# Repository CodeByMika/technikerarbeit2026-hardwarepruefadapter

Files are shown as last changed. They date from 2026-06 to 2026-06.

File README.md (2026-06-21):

# 🛠️ Hardware Prüfadapter







> **Portfolio-Projekt:** Dieses Repository enthält die vollständige Hard- und Softwareentwicklung eines universellen Hardware-Prüfadapters. Das Projekt entstand als Abschluss-/Technikerprojekt im Rahmen meiner Ausbildung zum staatlich geprüften Techniker Elektrotechnik (Profil: Softwareentwicklung).

---

## 📖 Projektübersicht

Der Hardware Prüfadapter ist ein Embedded-System auf Basis eines ESP32-S3, das entwickelt wurde, um externe Hardwarekomponenten und Baugruppen automatisiert zu testen und zu simulieren. Das System stellt eine Brücke zwischen analoger/digitaler Hardware und modernen Web-Technologien dar.

Das Hauptaugenmerk der Entwicklung lag auf einer **sauberen Systemarchitektur (Clean Architecture)**, extremer Ausfallsicherheit (Fail-Safe-Mechanismen) und einer hohen Testabdeckung durch systemunabhängiges Unit-Testing (TDD).

<p align="center">
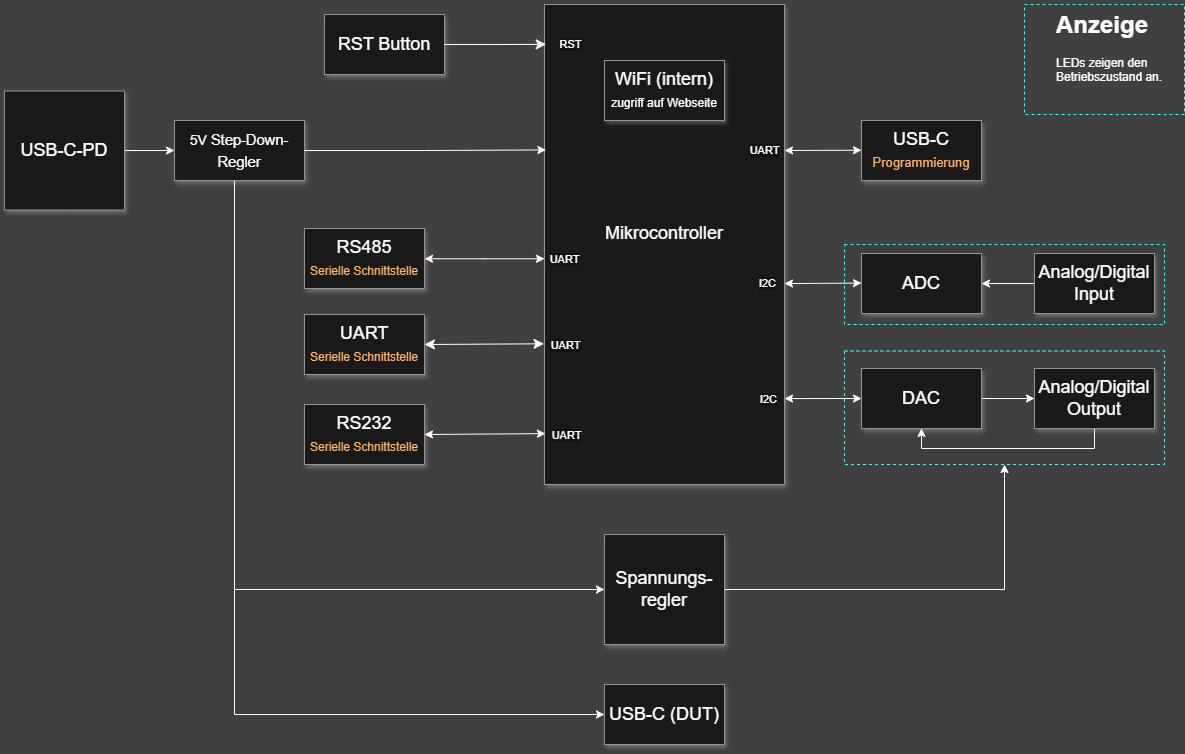
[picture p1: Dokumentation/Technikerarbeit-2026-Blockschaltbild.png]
Blockschaltbild
  

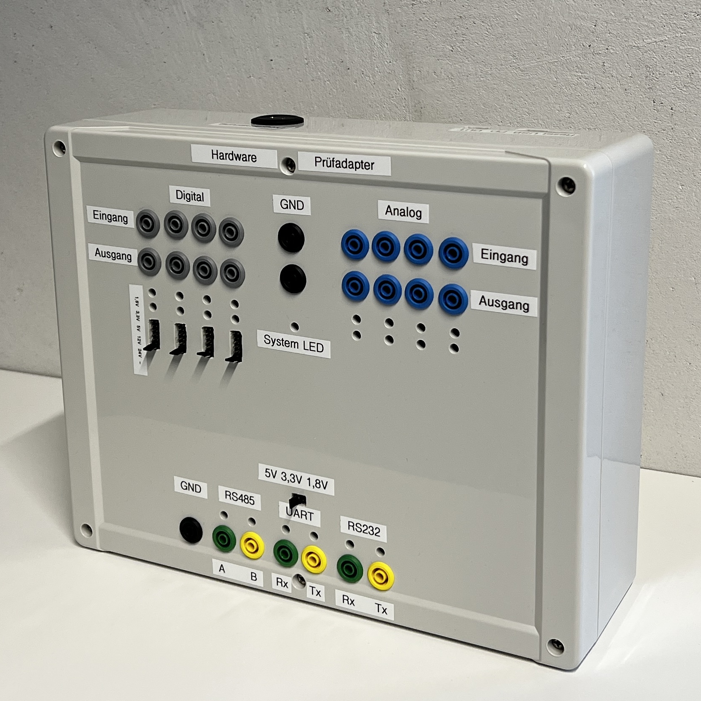
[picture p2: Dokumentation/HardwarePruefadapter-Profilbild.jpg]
Prüfadapter
  
  
  </p>

## ✨ Kernfunktionen & Features

### 💻 Software (VS Code)
* **Clean Architecture:** Strikte Trennung von Hardware-Treibern (Adaptern) und Business-Logik. Alle Logik-Komponenten sind plattformunabhängig in C++17 geschrieben.
* **Web-Dashboard:** Eine eingebettete Single-Page-Application (HTML/CSS/JS) direkt auf dem Mikrocontroller zur Steuerung und Überwachung der I/Os.
* **RESTful OpenAPI:** Bereitstellung einer API zur Automatisierung sowie Server-Sent Events (SSE) für ein Live-Terminal und Echtzeit-Log-Streaming.

### 🔌 Hardware (KiCad)
* **Herzstück:** ESP32-S3 für Netzwerkkommunikation und Logik.
* **Peripherie über I²C:**
  * ADCs (ADS1115) für Spannungsmessung.
  * DAC (DAC8574) zur Ausgabe analoger Spannung.
  * LED-Treiber (LP5018) für das Status-Feedback direkt am Gerät.
* **Externe Schnittstellen:** UART, RS232, RS485 für externe Gerätekommunikation.
>**Wichtig:** Hardwareänderungshinweise beachten, diese sind in der V1.0 nicht enthalten.

## 🏗️ Software-Architektur

Die Firmware basiert auf dem **EVA-Prinzip** (Eingabe - Verarbeitung - Ausgabe) und läuft in einem deterministischen Zyklus.

1. **Input Sequence:** Auslesen der ADCs, serielle Puffer leeren, asynchrone Befehle aus der Web-API (`Mailbox`) abholen.
2. **Process Sequence:** Abgleich der Daten im `ProcessImager`, Anwenden der Filter, Auswerten der Safety-Regeln (Überspannung, Kurzschluss).
3. **Output Sequence:** Setzen der DACs, Schalten der physikalischen GPIOs, Update der Status-LEDs.

Alle Hardware-Abhängigkeiten werden über Interfaces injiziert (Dependency Injection), wodurch die gesamte Logik auf dem PC simuliert und mit **GoogleTest** geprüft werden kann.

## 🛠️ Lokale Entwicklung & Testing

Das Projekt nutzt **PlatformIO** und ein `Makefile` für reibungslose Entwicklung unter Linux/WSL2 und Windows.

## 👨‍💻 Über den Autor

Dieses Projekt dient als praktischer Nachweis meiner Fähigkeiten im Bereich der hardwarenahen Softwareentwicklung, Systemarchitektur und Schaltungsentwicklung.

## ⚖️ Rechtliches & Haftungsausschluss (Disclaimer)

**Zweck des Projekts:** Dieses Projekt wurde ausschließlich zu Bildungs- und Demonstrationszwecken im Rahmen einer Weiterbildung zum staatlich geprüften Techniker entwickelt. Es handelt sich hierbei **nicht** um ein geprüftes, zertifiziertes oder für den produktiven Einsatz im industriellen oder privaten Umfeld zugelassenes Endprodukt.

**Haftungsausschluss:** Die Nutzung der in diesem Repository bereitgestellten Informationen, Quellcodes (Software) und Hardware-Designs (Schaltpläne, Gerber-Daten, KiCad-Files) erfolgt **ausschließlich auf eigene Gefahr**.

* Der Autor übernimmt keinerlei Gewähr für die Aktualität, Korrektheit, Vollständigkeit, Qualität oder Sicherheit der bereitgestellten Informationen.
* Haftungsansprüche gegen den Autor, welche sich auf Schäden materieller, immaterieller, personeller oder finanzieller Art beziehen, die durch die Nutzung oder Nichtnutzung der dargebotenen Informationen bzw. durch die Nutzung fehlerhafter und unvollständiger Informationen verursacht wurden, sind grundsätzlich ausgeschlossen.
* Beim Nachbau oder Betrieb der Hardware wird mit teilweise gefährlichen elektrischen Spannungen gearbeitet. Ein Nachbau darf nur von qualifiziertem Fachpersonal unter Einhaltung geltender VDE- und Sicherheitsvorschriften durchgeführt werden.

**Urheberrecht:** Alle Rechte an diesem Projekt, dem Quellcode und dem Hardware-Design liegen, sofern nicht anders durch Lizenzen von Drittanbietern angegeben (z.B. Bibliotheken im `/lib` Ordner), beim Autor.

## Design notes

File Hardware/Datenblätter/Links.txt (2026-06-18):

ZDiode_24V_mmsz5225_to_mmsz5267		https://www.mouser.de/ProductDetail/Vishay/MMSZ5226C-HE3_A-08?qs=Imq1NPwxi774wPyD3tjngw%3D%3D

MOSFETs:

24V:
TSM05N03		https://www.reichelt.de/de/de/shop/produkt/mosfet_n-ch_30v_5a_0_046r_sot-223-254918	
TSM042N03CS		https://www.reichelt.de/de/de/shop/produkt/mosfet_n-ch_30v_30a_7w_0_0042r_so-8-379909
IRF 7832PbF		https://www.reichelt.de/de/de/shop/produkt/mosfet_n-ch_30v_20a_2_5w_so-8-129794
IRLR8743PbF		https://www.reichelt.de/de/de/shop/produkt/mosfet_n-ch_30v_160a_135w_to-251aa-90380

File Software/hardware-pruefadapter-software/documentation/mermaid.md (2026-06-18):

```mermaid
flowchart LR
    %% Styling der Blöcke
    classDef ext fill:#f9f9f9,stroke:#666,stroke-width:2px,color:#333
    classDef switch fill:#ffebee,stroke:#c62828,stroke-width:2px,color:#b71c1c
    classDef ctrl fill:#2b4a7d,stroke:#1a2b4c,stroke-width:2px,color:#fff
    classDef power fill:#e7f9e7,stroke:#2b7d4a,stroke-width:2px,color:#1a4c2b
    classDef config fill:#fff3e0,stroke:#d48806,stroke-width:2px,color:#875604,stroke-dasharray: 5 5

    %% Nodes
    USBC["<b>USB-C Buchse</b>"]:::ext
    Switch{"<b>Schalter</b>"}:::switch
    Matrix[/"<b>Widerstandsmatrix</b><br/>(Spannungs- & Stromlimit)"/]:::config
    PDCtrl{{"<b>USB-PD Controller</b>"}}:::ctrl
    
    Reg5V["<b>Hauptregler</b><br/>(5V)"]:::power
    
    subgraph Verteilung ["Spannungsverteilung"]
        direction TB
        StepUp["<b>Step-Up Wandler</b><br/>(12V / 24V)"]:::power
        StepDown["<b>Step-Down Wandler</b><br/>(3,3V / 1,8V)"]:::power
    end

    %% Verbindungen
    USBC <==> Switch
    Switch <==>|"PD-Protokoll<br/>Aushandlung"| PDCtrl
    
    Matrix -.->|"konfiguriert"| PDCtrl
    
    PDCtrl ===>|"VBUS<br/>(max. 15V / 3,9 A)"| Reg5V
    
    Reg5V ===>|5V| StepUp
    Reg5V ===>|5V| StepDown

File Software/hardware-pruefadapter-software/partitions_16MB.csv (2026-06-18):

# Name | Type | SubType | Offset | Size | Flags
nvs | data | nvs |  | 0x6000
phy_init | data | phy |  | 0x1000
otadata | data | ota |  | 0x2000
app0 | app | factory |  | 6M
app1 | app | ota_0 |  | 6M
spiffs | data | spiffs |  | 3M
coredump | data | coredump |  | 64K

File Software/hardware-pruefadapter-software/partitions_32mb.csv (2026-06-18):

# Name | Type | SubType | Offset | Size | Flags
nvs | data | nvs |  | 0x6000
phy_init | data | phy |  | 0x1000
otadata | data | ota |  | 0x2000
app0 | app | factory |  | 2M
app1 | app | ota_0 |  | 10M
app2 | app | ota_1 |  | 10M
spiffs | data | spiffs |  | 9M
coredump | data | coredump |  | 64K

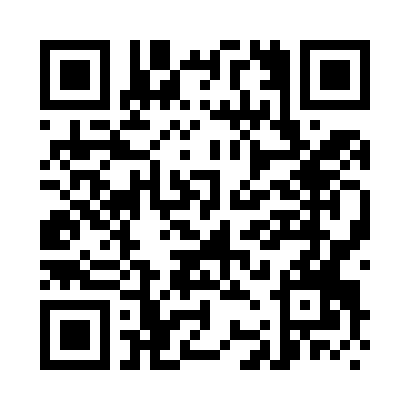
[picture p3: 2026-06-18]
Software/hardware-pruefadapter-software/demo/1_WLAN_Login.png

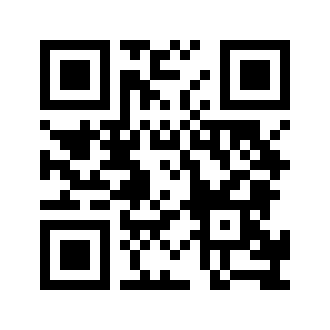
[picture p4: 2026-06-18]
Software/hardware-pruefadapter-software/demo/2_Dashboard_Link.png

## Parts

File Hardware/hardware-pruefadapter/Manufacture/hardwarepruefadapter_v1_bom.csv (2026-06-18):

Designator | Footprint | Quantity | Value | LCSC Part #
C1001, C1002, C1004, C303 | 0805 | 4 | 1uF/50V | C28323
C1003, C1006, C1008, C804, C806 | 0805 | 5 | 10uF/25V | C15850
C1005, C1007, C1009, C1301, C1302, C1303, C1304, C1305, C203, C204, C205, C401, C405, C502, C602, C803, C805, C905, C908 | 0805 | 19 | 100nF/50V | C1711
C1101, C201, C802, C807 | 1206 | 4 | 100uF/6.3V | C15008
C1201, C202 | 1206 | 2 | 100nF/50V | C24497
C301, C302 | 1206 | 2 | 4.7uF/25V | C1872
C304 | 1206 | 1 | 1uF/50V | C1848
C305, C306 | 0603 | 2 | 100nF/50V | C14663
C307, C308 | 0603 | 2 | 1uF/50V | C15849
C402, C403, C404, C413, C415 | 1206 | 5 | 4.7uF/50V | C29823
C406 | 0805 | 1 | 100pF/50V | C1790
C407 | 1206 | 1 | 47uF/10V | C96123
C408, C409 | 0805 | 2 | 2.2uF/25V | C19110
C410 | 1206 | 1 | 10uF/16V | C1849
C411 | 1206 | 1 | 22uF/25V | C12891
C412 | 0805 | 1 | 3.3pF/50V | C170106
C414, C419 | 0805 | 2 | 4.7pF/50V | C1820
C416, C417 | 0805 | 2 | 4.7uF/25V | C1779
C418 | 0805 | 1 | 680pF/50V | C1754
C501, C503, C505, C506, C601, C603, C605, C606, C901, C902, C906, C907, C909, C910, C911, C912 | 0805 | 16 | 1µF/50V | C28323
D1001, D1002, D1003, D1004, D1005, D1006, D1007, D1008, D1009, D1010, D1011, D1012, D1013, D1014, D1015, D1016, D1017 | WL-SFTW_3528_PLCC4 | 17 | 150352M173300 | C6785090
D1101, D1203, D1303 | WL-SMCW_0603_Yellow | 3 | 150060YS75000 | C6784997
D1102, D1204, D1304 | WL-SMCW_0603_Green | 3 | 150060GS75000 | C5252984
D1201, D1202 | D_SMA | 2 | SMAJ12A | C28613
D1301, D1302 | D_SMA | 2 | SMAJ15CA | C46985
D301 | D_SMA | 1 | SMAJ20A | C10763
D302 | D_SMA | 1 | SMAJ15A | C23424
D304 | WL-SMSW_1204_A | 1 | E6C1204VGAC1UDA | C375482
D401, D402 | DIO_BAS716_115 | 2 | BAS716,115 | C282366
D403 | D_SOD-323F | 1 | PMEG4010CEJ,115 | C50704
D501, D502, D503, D504, D601, D602, D603, D604, D801, D802, D803, D804, D901, D902, D903, D904, D905, D906, D907, D908 | TSOT-23 | 20 | BAV199LT1G | C145516
D701, D703, D705, D707, D709, D711, D713, D715 | SOT95P240X111-3N | 8 | BZX84C10LT1G | C82476
D702, D706, D710, D714 | D_SMA | 4 | SMAJ5.0A | C10758
D704, D708, D712, D716 | D_SMA | 4 | SMAJ24A | C10769
D805 | D_SMA | 1 | SMAJ26A | C49370
F1201, F1202 | 1206 | 2 | 1206L010/60WR | C2153714
F801, F802, F803, F804 | FUSC1607X85N | 4 | 0ZCM0002FF2G | C5299556
IC1001, IC1002, IC1003 | VQFN-32_LP5018RSMR | 3 | LP5018RSMR | C2653373
J1101 | 61300621121 | 1 | 6130XX21121_61300621121 | C5140604
J1102, J1201, J1301 | PHOENIX_1861933 | 3 | 1861933 | C5483323
J1202 | PHOENIX_1933192 | 1 | 1933192 | C5266027
J201, J202, J203, J204 | 61201621621 | 4 | 5103308-3 | C305956
J301, J401 | AMPHENOL_12402012E212A | 2 | 12402012E212A | C5150972
J402 | PHOENIX_1861946 | 1 | 1861946 | C6368767
J501, J601, J710, J801 | PHOENIX_1861959 | 4 | 1861959 | C6656102
J702, J704, J706, J708 | 61301221121 | 4 | 6130XX21121_61301221121 | C6699258
L1201, L1202 | 1206 | 2 | CBM321609U181T | C391192
L301, L303 | WE-MPSB_1812 | 2 | WE-MPSB_1812 | C5155961
L302 | WE-MAPI_4020 | 1 | XAL4020-122MEC | C19191653
L401 | INDDFN750X750X310-2N | 1 | 3.3uH | C5448588
L402 | WE-LQS_3015 | 1 | 10uH | C1329386
L403 | WE-LQS_5020 | 1 | 10uH | C7193153
Q301 | SOT-23 | 1 | BSS123 | C8491
Q701, Q702, Q703, Q704, Q705, Q706, Q707, Q708 | SOT-23 | 8 | BS170FTA | C5236685
R1001, R1002, R1008, R515, R615, R922, R928 | 0805 | 7 | 3.3k | C26010
R1003, R1004, R1005, R1009, R1010, R1201, R210, R301, R305, R407, R420, R421, R509, R609, R701, R704, R705, R706, R708, R710, R711, R712, R714, R715, R716, R717, R719, R720, R721, R723, R724, R725, R726, R728, R729, R730, R732, R733, R734, R735, R737, R738, R812 | 0805 | 43 | 10k | C149881
R1011, R1012, R1013, R1014, R505, R604, R801, R813, R903, R904 | 0805 | 10 | 0R | C17477
R1101 | 0805 | 1 | 1M | C17514
R1102, R208, R209, R802, R807, R816, R823 | 0805 | 7 | 200k | C17539
R1103 | 0805 | 1 | 360K | C17645
R1104, R1105, R1107, R1108 | 0805 | 4 | 4.7k | C17673
R1106, R404, R806, R815, R822, R827 | 0805 | 6 | 20K | C4328
R1109, R1110, R1203, R1204, R1301, R1302, R315, R503, R508, R516, R519, R603, R608, R616, R619, R739, R740, R741, R742, R905, R906, R911, R912, R924, R925, R931, R933 | 0805 | 27 | 1k | C17513
R1202 | 1206 | 1 | 1R | C17928
R1205 | 0805 | 1 | 390R | C17655
R202, R203, R204, R205, R206, R207, R211, R212, R513, R613, R919, R923 | 0805 | 12 | 2.2k | C17520
R302 | 0805 | 1 | 51k | C17737
R303 | 0603 | 1 | 1k | C21190
R304 | 0603 | 1 | 10k | C25804
R306 | 0603 | 1 | 4.7k | C23162
R308, R309, R312 | 0603 | 3 | 5.1k | C23186
R310, R311 | 0603 | 2 | 0R | C15402
R313 | 0603 | 1 | 2.4k | C22940
R405 | 0805 | 1 | 68k | C17801
R406, R418 | 0805 | 2 | 5.1k | C27834
R410, R417 | 0805 | 2 | 100k | C149504
R411, R502, R506, R514, R518, R602, R606, R614, R618, R901, R902, R909, R910, R920, R921, R929, R930 | 0805 | 17 | 150k | C17470
R412 | 0805 | 1 | 110k | C17422
R415 | 0805 | 1 | 1.3M | C26109
R416 | 0805 | 1 | 180k | C101955
R419 | 0805 | 1 | 160k | C17485
R422, R423 | 0805 | 2 | 56k | C17756
R424 | 1206 | 1 | 0R | C17888
R504, R512, R517, R520, R605, R612, R617, R620, R804, R814, R819, R824, R907, R908, R913, R916, R926, R927, R932, R934 | 0805 | 20 | 30k | C17621
R702 | 1206 | 1 | 1k | C4410
R703, R709, R713, R718, R722, R727, R731, R736 | RESC3216X125N | 8 | 0ZCJ0010FF2E | C194142
R707 | 1206 | 1 | 24k | C17960
R803, R805, R817, R818 | 2512 | 4 | 330R | C19866
S201 | 4363X10458XX | 1 | 436331045822 | C6089591
U1101, U202, U203 | SOP65P400X130-8N | 3 | LSF0102DCTR | C132024
U1201 | SOTFL50P160X60-8N | 1 | THVD1406DR | C5215918
U1202 | MFSOP6-4_4.4x3.6mm_P1.27mm | 1 | TLP175A(TPL,E | C141522
U1301 | SOP65P640X120-16N | 1 | TRS3232EIPWR | C2652868
U301 | SOIC127P600X175-8N | 1 | IRF9358TRPBF | C537847
U302 | USON-10_2.5x1.0mm_P0.5mm | 1 | TPD4EUSB30DQAR | C90627
U303 | QFN-24-1EP_4x4mm_P0.5mm_EP2.75x2.75mm | 1 | CYPD3177-24LQXQ | C2959321
U401 | CONV_TPS56637RPAR | 1 | TPS56637RPAR | C841386
U402 | SOT-23-5 | 1 | TLV75801PDBVT | C2868412
U403 | SOT-23-5 | 1 | TPS61041DBVR K | C9846
U404 | SON65P200X200X80-7N | 1 | TPS61170DRVR | C15163
U502, U602, U903, U904 | TSSOP-10_3x3mm_P0.5mm | 4 | ADS1115IDGST | C468683
U701, U702, U703, U704, U705, U706, U707, U708 | SOT103P240X110-3N | 8 | DMP3130L-7 | C155233
U802, U804 | SOIC127P600X175-8N | 2 | OPA2990IDR | C2058283
U803 | SOP65P640X120-16N | 1 | DAC8574IPWR | C2864663
VR401 | VREG_LM1117MPX-3.3_NOPB | 1 | LM1117MPX-3.3/NOPB | C9662

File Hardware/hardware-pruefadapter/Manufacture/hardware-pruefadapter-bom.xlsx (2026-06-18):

ID | Bezeichner | Footprint | Stückzahl | Bezeichnung | Anbieter und Referenz
1 | R502,R902,R602,R606,R618,R909,R411,R901,R920,R614,R930,R514,R910,R518,R506,R921,R929 | R_0805_2012Metric | 17 | 150k
2 | R1303,R1206,R501,R402,R1006,R403,R424,R1007,R408,R401,R935,R414,R1111,R409 | R_1206_3216Metric | 14 | 0R
3 | D903,D907,D503,D602,D801,D601,D803,D804,D904,D908,D504,D902,D905,D502,D501,D906,D901,D604,D603,D802 | DIO_BAV99 | 20 | BAV99
4 | S201 | 4363X10458XX | 1 | 436331045822
5 | R919,R613,R513,R923 | R_0805_2012Metric | 4 | 2,2K
6 | R209,R1102,R802,R823,R208,R807,R816 | R_0805_2012Metric | 7 | 200k
7 | R713,R718,R731,R736,R709,R703,R722,R727 | RESC3216X125N | 8 | 0ZCJ0010FF2E
8 | C414,C419 | C_0805_2012Metric | 2 | 4.7pF
9 | R735,R720,R721,R738,R737,R1003,R705,R609,R1004,R723,R407,R726,R808,R734,R712,R732,R701,R729,R728,R730,R717,R1009,R509,R421,R714,R1005,R210,R809,R706,R305,R301,R810,R715,R420,R708,R716,R1201,R724,R725,R710,R711,R733,R812,R704,R811,R1010,R719 | R_0805_2012Metric | 47 | 10k
10 | D705,D713,D703,D701,D707,D715,D711,D709 | SOT95P240X111-3N | 8 | BZX84C10LT1G
11 | R805,R818,R817,R803 | R_2512_6332Metric | 4 | 330
12 | R932,R908,R504,R517,R804,R512,R913,R916,R934,R927,R814,R617,R620,R612,R520,R907,R819,R605,R926,R824 | R_0805_2012Metric | 20 | 30k
13 | R415 | R_0805_2012Metric | 1 | 1,3M
14 | R516,R933,R1302,R739,R1110,R925,R924,R503,R1109,R508,R1203,R905,R1301,R931,R741,R608,R906,R911,R519,R912,R315,R619,R616,R603,R740,R1204,R742 | R_0805_2012Metric | 27 | 1k
15 | R303 | R_0603_1608Metric | 1 | 1k
16 | U1202 | MFSOP6-4_4.4x3.6mm_P1.27mm | 1 | TLP175A
17 | U703,U701,U705,U702,U708,U707,U704,U706 | SOT103P240X110-3N | 8 | DMP3130L-7
18 | C1008,C804,C1003,C1006,C806 | C_0805_2012Metric | 5 | 10uF
19 | C205,C203,C401,C1009,C204,C1007,C405,C1005 | C_0805_2012Metric | 8 | 100nF
20 | R1012,R604,R903,R904,R1013,R1014,R505,R1011 | R_0805_2012Metric | 8 | 0
21 | C1002,C1004,C1001 | C_0805_2012Metric | 3 | 1uF
22 | J601,J501,J801,J710 | PHOENIX_1861959 | 4 | 1861959
23 | C901,C506,C501,C606,C909,C911,C907,C906,C503,C601,C902,C605,C912,C910,C603,C505 | C_0805_2012Metric | 16 | 1µF
24 | R203,R204,R207,R202,R205,R212,R211,R206 | R_0805_2012Metric | 8 | 2,2k
25 | J1102,J1301,J1201 | PHOENIX_1861933 | 3 | 1861933
26 | R1002,R1001,R1008 | R_0805_2012Metric | 3 | 3,3k
27 | D712,D708,D704,D716 | D_SMA | 4 | SMAJ24A
28 | R1101 | R_0805_2012Metric | 1 | 1M
29 | C412 | C_0805_2012Metric | 1 | 3.3pF
30 | R1105,R1104,R1108,R1305,R1207,R1107,R1304,R1208 | R_0805_2012Metric | 8 | 4,7k
31 | D1201,D1202 | D_SMA | 2 | SMAJ12A
32 | L302 | WE-MAPI_4020 | 1 | WE-MAPI_4020
33 | D702,D706,D714,D710 | D_SMA | 4 | SMAJ5.0A
34 | R826,R813,R201,R801,R413,R825 | R_0805_2012Metric | 6 | 0R
35 | R1106 | R_0805_2012Metric | 1 | 20K
36 | R302 | R_0805_2012Metric | 1 | 51k
37 | J1302,J403 | PinHeader_1x06_P2.54mm_Vertical | 2 | Conn_01x06_Pin
38 | R1205 | R_0805_2012Metric | 1 | 390R
39 | J205 | 61301421121 | 1 | Conn_02x07_Counter_Clockwise
40 | R422,R423 | R_0805_2012Metric | 2 | 56k
41 | R419 | R_0805_2012Metric | 1 | 160k
42 | C502,C803,C1302,C1304,C1305,C905,C908,C1303,C1301,C805,C602 | C_0805_2012Metric | 11 | 0.1uF
43 | R928,R922,R615,R515 | R_0805_2012Metric | 4 | 3,3K
44 | C201,C802,C1101,C807 | C_1206_3216Metric | 4 | 100uF
45 | D302 | D_SMA | 1 | SMAJ15A
46 | R702 | R_1206_3216Metric | 1 | 1k
47 | C306,C305 | C_0603_1608Metric | 2 | 100nF
48 | C407 | C_1206_3216Metric | 1 | 47uF
49 | R601 | R_1206_3216Metric | 1 | 0
50 | Q703,Q704,Q707,Q701,Q706,Q705,Q708,Q702 | SOT-23 | 8 | BS170FTA
51 | R406,R418 | R_0805_2012Metric | 2 | 5,1k
52 | U1201 | SOTFL50P160X60-8N | 1 | THVD1406DR
53 | U401 | CONV_TPS56637RPAR | 1 | TPS56637RPAR
54 | U301 | SOIC127P600X175-8N | 1 | IRF9358TRPBF
55 | U1301 | SOP65P640X120-16N | 1 | TRS3232EIPWR
56 | L402 | L_1206_3216Metric | 1 | 6.8µH
57 | U404 | SON65P200X200X80-7N | 1 | TPS61170DRVR
58 | C307,C308 | C_0603_1608Metric | 2 | 1uF
59 | F801,F804,F802,F803 | FUSC1607X85N | 4 | 0ZCM0002FF2G
60 | C301 | C_1206_3216Metric | 1 | 4uF/25V
61 | C1201,C202 | C_1206_3216Metric | 2 | 100nF
62 | U903,U502,U904,U602 | TSSOP-10_3x3mm_P0.5mm | 4 | ADS1115IDGS
63 | R827,R404,R815,R822,R806 | R_0805_2012Metric | 5 | 20k
64 | U303 | QFN-24-1EP_4x4mm_P0.5mm_EP2.75x2.75mm | 1 | CYPD3177-24LQXQ
65 | R707 | R_1206_3216Metric | 1 | 24k
66 | C406 | C_0805_2012Metric | 1 | 100pF
67 | R307,R314,R311,R310 | R_0603_1608Metric | 4 | 0
68 | Q301 | SOT-23 | 1 | BSS123
69 | D805 | D_SMA | 1 | SMAJ26A
70 | L1201,L1202 | L_1206_3216Metric | 2 | 180R
71 | U403 | SOT-23-5 | 1 | TPS61041DDC
72 | TP302 | TestPoint_Pad_D1.5mm | 1 | TestPoint_VBUS-SW
73 | C402,C403,C404 | C_1206_3216Metric | 3 | 4u7
74 | C413 | C_1206_3216Metric | 1 | 4.7uF / 25V
75 | J202,J204,J201,J203 | 61201621621 | 4 | 6120XX21621_61201621621
76 | R416 | R_0805_2012Metric | 1 | 180k
77 | J402 | PHOENIX_1861946 | 1 | 1861946
78 | TP202,TP201 | TestPoint_Pad_D1.5mm | 2 | ~
79 | U203,U1101,U202 | SOP65P400X130-8N | 3 | LSF0102DCTR
80 | U802,U804 | SOIC127P600X175-8N | 2 | OPA2990IDR
81 | C417 | C_0805_2012Metric | 1 | 4.7uF / 16V
82 | D1301,D1302 | D_SMA | 2 | SMAJ15CA
83 | C415 | C_1206_3216Metric | 1 | 4.7uF
84 | J301,J401 | AMPHENOL_12402012E212A | 2 | 12402012E212A
85 | D402,D401 | DIO_BAS716_115 | 2 | BAS716_115
86 | F1202,F1201 | Fuse_1206_3216Metric | 2 | Polyfuse_Small
87 | U302 | USON-10_2.5x1.0mm_P0.5mm | 1 | TPD4EUSB30
88 | R306 | R_0603_1608Metric | 1 | 4k7
89 | C410 | C_1206_3216Metric | 1 | 10uF
90 | TP203 | TestPoint_Pad_D1.5mm | 1 | GPIO43
91 | R312,R308,R309 | R_0603_1608Metric | 3 | 5k1
92 | VR401 | VREG_LM1117MPX-3.3_NOPB | 1 | LM1117MPX-3.3_NOPB
93 | R405 | R_0805_2012Metric | 1 | 68k
94 | L303,L301 | WE-MPSB_1812 | 2 | WE-MPSB_1812
95 | TP301 | TestPoint_Pad_D1.5mm | 1 | TestPoint_VBUS
96 | C409,C408 | C_0805_2012Metric | 2 | 2.2uF
97 | C303 | C_0805_2012Metric | 1 | 1u
98 | R412 | R_0805_2012Metric | 1 | 110k
99 | C416 | C_0805_2012Metric | 1 | 4.7uF
100 | U402 | SOT-23-5 | 1 | TLV75801PDBV
101 | R417,R410 | R_0805_2012Metric | 2 | 100k
102 | C302 | C_1206_3216Metric | 1 | 4u7/25V
103 | L403 | L_1206_3216Metric | 1 | 10µH
104 | D301 | D_SMA | 1 | SMAJ20A
105 | R1103 | R_0805_2012Metric | 1 | 360K
106 | R304 | R_0603_1608Metric | 1 | 10k
107 | J1202 | PHOENIX_1933192 | 1 | 1933192
108 | L401 | L_1206_3216Metric | 1 | 3.3uH
109 | C418 | C_0805_2012Metric | 1 | 680pF
110 | TP204 | TestPoint_Pad_D1.5mm | 1 | GPIO44
111 | R1202 | R_1206_3216Metric | 1 | 1R
112 | D403 | D_SOD-323F | 1 | PMEG4010CEJ
113 | U201 | ESP32-S3-DEVKITC-1-N8R8 | 1 | ESP32-S3-DEVKITC-1
114 | C304 | C_1206_3216Metric | 1 | 1u
115 | C411 | C_1206_3216Metric | 1 | 22uF
116 | R313 | R_0603_1608Metric | 1 | 2k4
117 | U803 | SOP65P640X120-16N | 1 | DAC8574IPWR
118 | D304 | WL-SMSW_1204_A | 1 | WL-SMSW_1204_A
119 | D1006,D1008,D1003,D1005,D1004,D1009,D1001,D1013,D1015,D1012,D1007,D1011,D1010,D1016,D1017,D1014,D1002 | WL-SFTW_3528_PLCC4 | 17 | WL-SFTW_3528_PLCC4
120 | J706,J708,J704,J702 | 61301221121 | 4 | 6130XX21121_61301221121
121 | D1204,D1102,D1304 | WL-SMCW_0603_Green | 3 | WL-SMCW_0603_Green
122 | D1303,D1101,D1203 | WL-SMCW_0603_Yellow | 3 | WL-SMCW_0603_Yellow
123 | IC1001,IC1002,IC1003 | SOP50P490X110-28N | 3 | LP5018DGSR
124 | J1101 | 61300621121 | 1 | 6130XX21121_61300621121

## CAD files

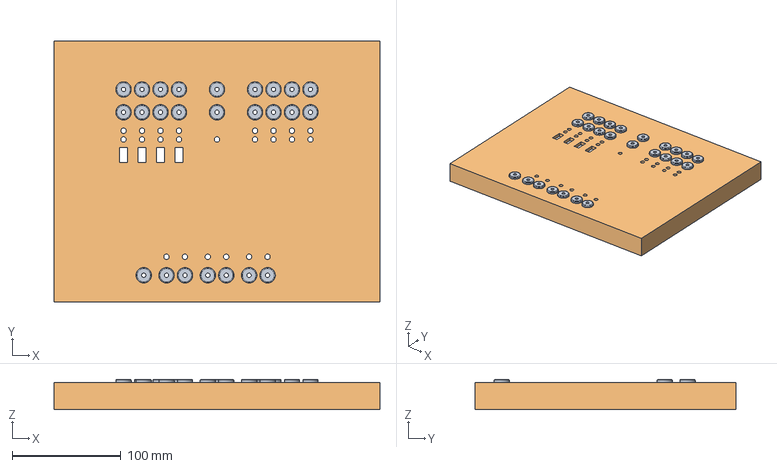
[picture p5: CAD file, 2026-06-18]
Gehause/Gehause_RSC_Hammond1555YGY.FCStd
300.0 x 240.0 x 27.8 mm
Bananenbuchsen
Deckel

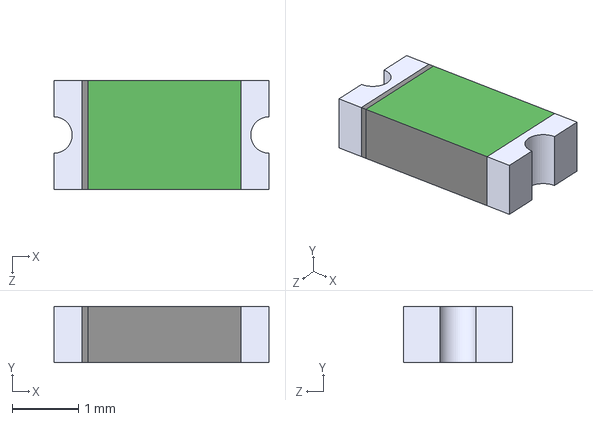
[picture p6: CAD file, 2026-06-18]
Hardware/Bauteildesigndaten/0ZCJ0010FF2E/0ZCJ0010FF2E.step
3.25 x 0.85 x 1.65 mm

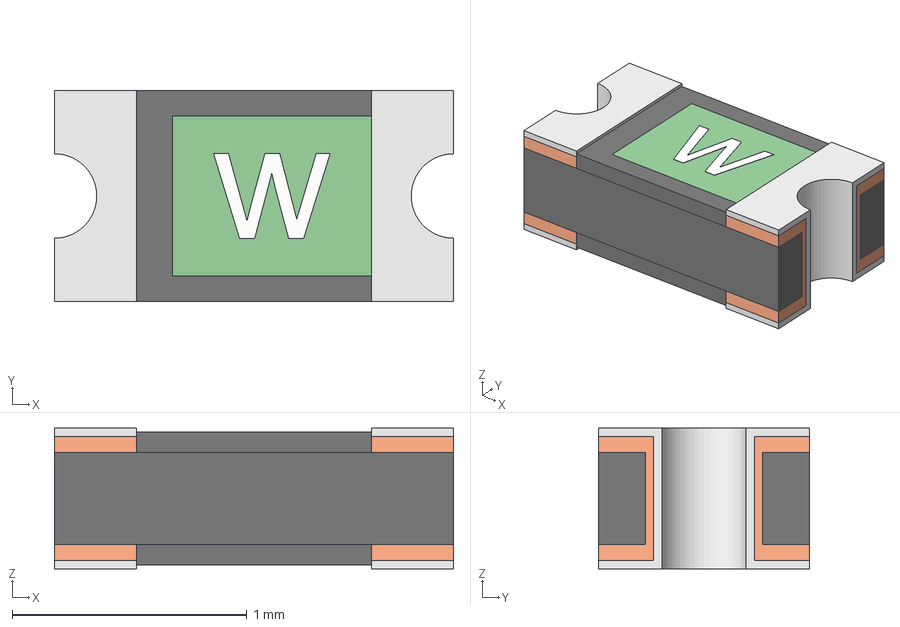
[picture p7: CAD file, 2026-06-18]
Hardware/Bauteildesigndaten/0ZCM0002FF2G/0ZCM0002FF2G.step
1.70 x 0.9 x 0.6 mm
0ZCM0002FF2G_PART1
0ZCM0002FF2G_PART2
0ZCM0002FF2G_PART3
0ZCM0002FF2G_PART4
0ZCM0002FF2G_PART5
0ZCM0002FF2G_PART6
0ZCM0002FF2G_PART7
0ZCM0002FF2G_PART8
0ZCM0002FF2G_PART9
0ZCM0002FF2G_PART10
0ZCM0002FF2G_PART11

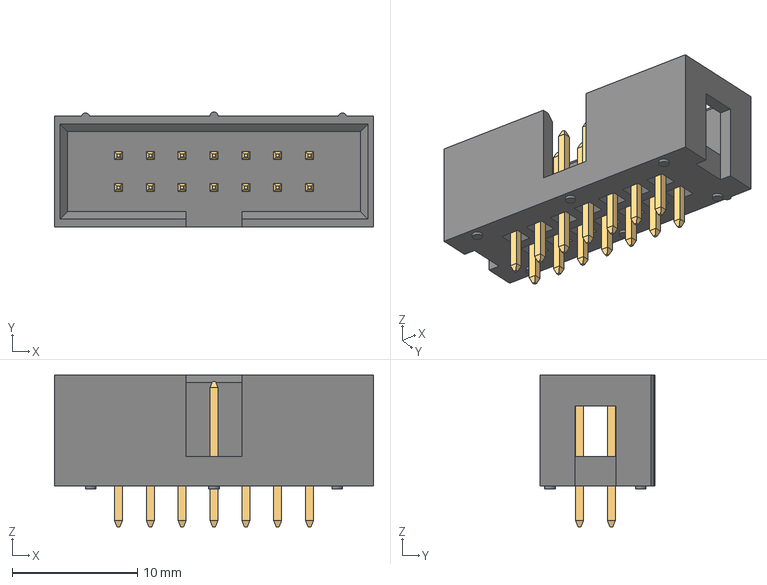
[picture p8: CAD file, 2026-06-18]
Hardware/Bauteildesigndaten/61201421621/6120XX21621_61201421621.step
25.4 x 9.18 x 12.1 mm
6120xx21621_PIN x 14

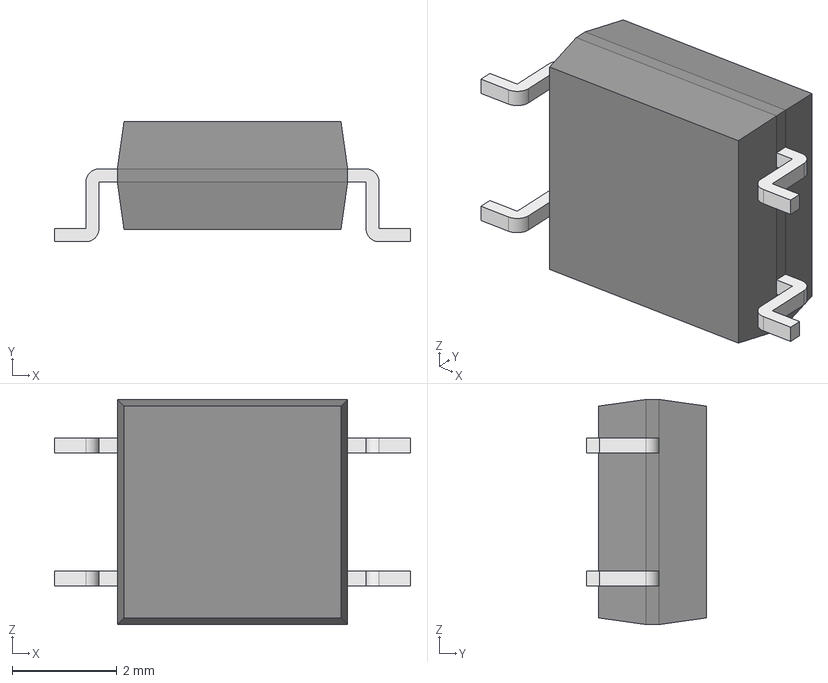
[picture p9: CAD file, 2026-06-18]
Hardware/Bauteildesigndaten/AQY212SX/AQY212SX.step
6.80 x 2.30 x 4.30 mm
Body001 (Mirror #1) x 2
XY-plane x 12
X-axis x 12

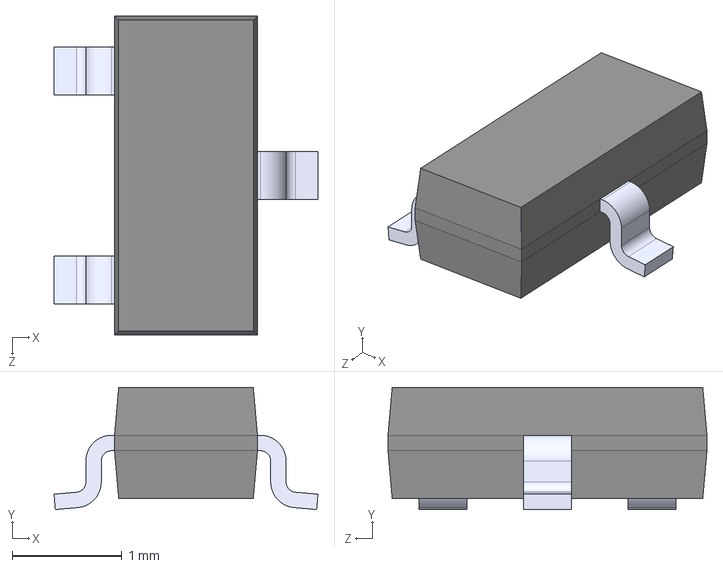
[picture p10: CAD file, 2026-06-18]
Hardware/Bauteildesigndaten/BZX84C10LT1G/BZX84C10LT1G.step
2.40 x 1.11 x 2.90 mm

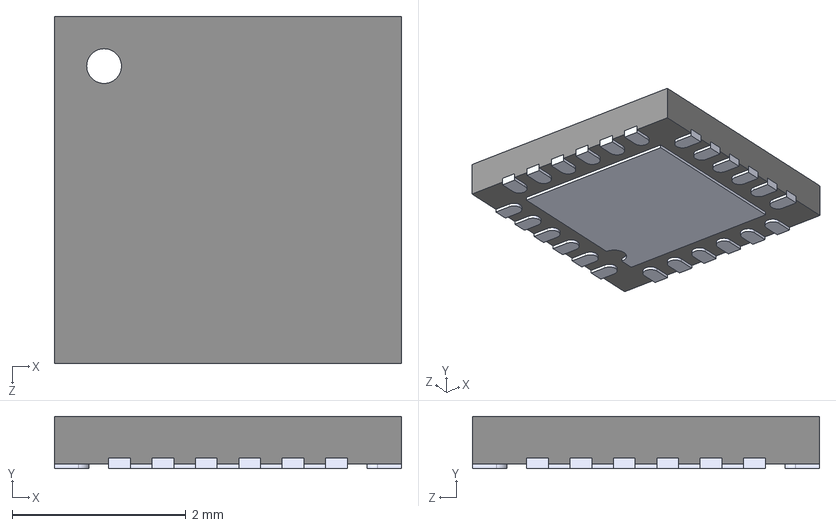
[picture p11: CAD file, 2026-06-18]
Hardware/Bauteildesigndaten/CYPD3177-24LQXQ/CYPD3177-24LQXQ--3DModel-STEP-510211.STEP
4.00 x 0.6 x 4.00 mm
EXPORT__Body__S01^QFN(2)_CYPD3177-24LQXQ
EXPORT__Body001__S01^QFN(2)_CYPD3177-24LQXQ
EXPORT__Body001__S02^QFN(2)_CYPD3177-24LQXQ
EXPORT__Body001__S03^QFN(2)_CYPD3177-24LQXQ
EXPORT__Body001__S04^QFN(2)_CYPD3177-24LQXQ
EXPORT__Body001__S05^QFN(2)_CYPD3177-24LQXQ
EXPORT__Body001__S06^QFN(2)_CYPD3177-24LQXQ
EXPORT__Body001__S07^QFN(2)_CYPD3177-24LQXQ
EXPORT__Body001__S08^QFN(2)_CYPD3177-24LQXQ
EXPORT__Body001__S09^QFN(2)_CYPD3177-24LQXQ
EXPORT__Body001__S10^QFN(2)_CYPD3177-24LQXQ
EXPORT__Body001__S11^QFN(2)_CYPD3177-24LQXQ
EXPORT__Body001__S12^QFN(2)_CYPD3177-24LQXQ
EXPORT__Body002__S01^QFN(2)_CYPD3177-24LQXQ
EXPORT__Body002__S02^QFN(2)_CYPD3177-24LQXQ
EXPORT__Body002__S03^QFN(2)_CYPD3177-24LQXQ
EXPORT__Body002__S04^QFN(2)_CYPD3177-24LQXQ
EXPORT__Body002__S05^QFN(2)_CYPD3177-24LQXQ
EXPORT__Body002__S06^QFN(2)_CYPD3177-24LQXQ
EXPORT__Body002__S07^QFN(2)_CYPD3177-24LQXQ
EXPORT__Body002__S08^QFN(2)_CYPD3177-24LQXQ
EXPORT__Body002__S09^QFN(2)_CYPD3177-24LQXQ
EXPORT__Body002__S10^QFN(2)_CYPD3177-24LQXQ
EXPORT__Body002__S11^QFN(2)_CYPD3177-24LQXQ
EXPORT__Body002__S12^QFN(2)_CYPD3177-24LQXQ
EXPORT__Body003__S01^QFN(2)_CYPD3177-24LQXQ
EXPORT__Body004__S01^QFN(2)_CYPD3177-24LQXQ

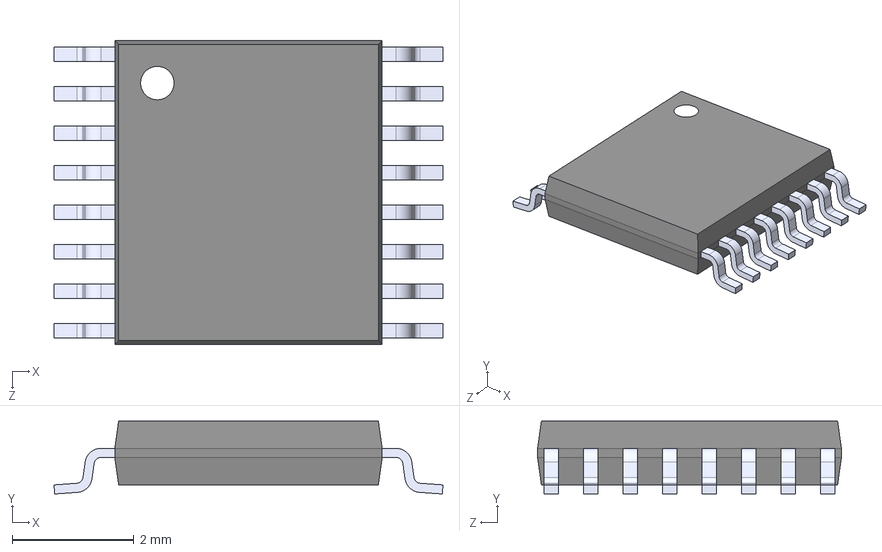
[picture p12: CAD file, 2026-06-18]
Hardware/Bauteildesigndaten/DAC8574IPWR/DAC8574IPWR.step
6.40 x 1.20 x 5.00 mm

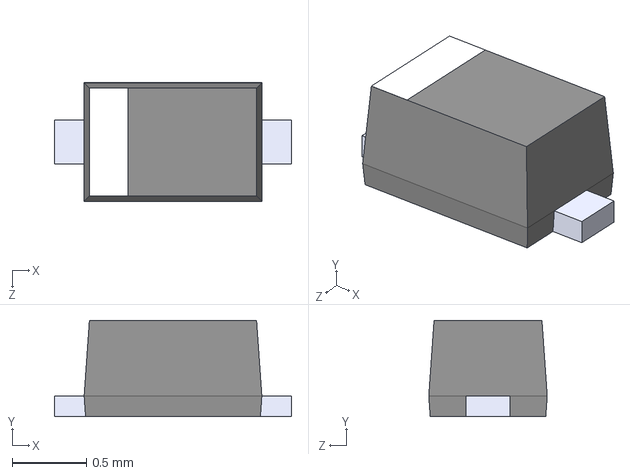
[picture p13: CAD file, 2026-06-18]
Hardware/Bauteildesigndaten/Dioden/BAS716_115/BAS716_115.step
1.60 x 0.65 x 0.8 mm

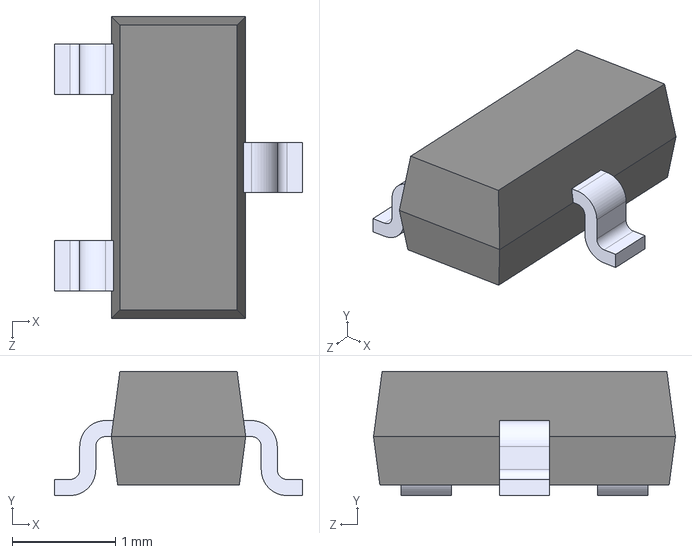
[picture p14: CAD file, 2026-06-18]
Hardware/Bauteildesigndaten/Dioden/BAT54S/BAT54S.step
2.40 x 1.20 x 2.92 mm

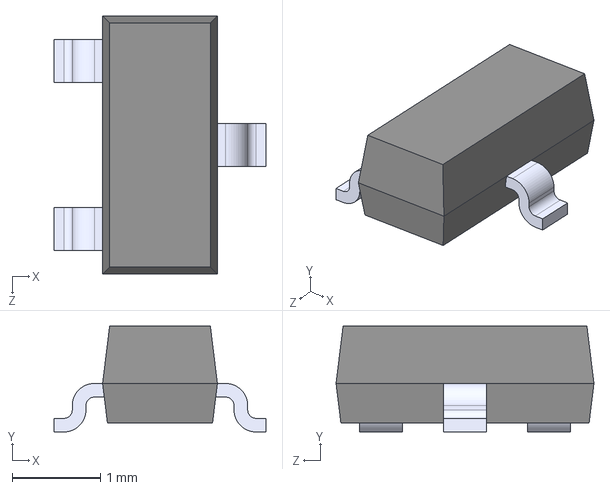
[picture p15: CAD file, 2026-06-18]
Hardware/Bauteildesigndaten/Dioden/BAV99/BAV99.step
2.40 x 1.20 x 2.92 mm

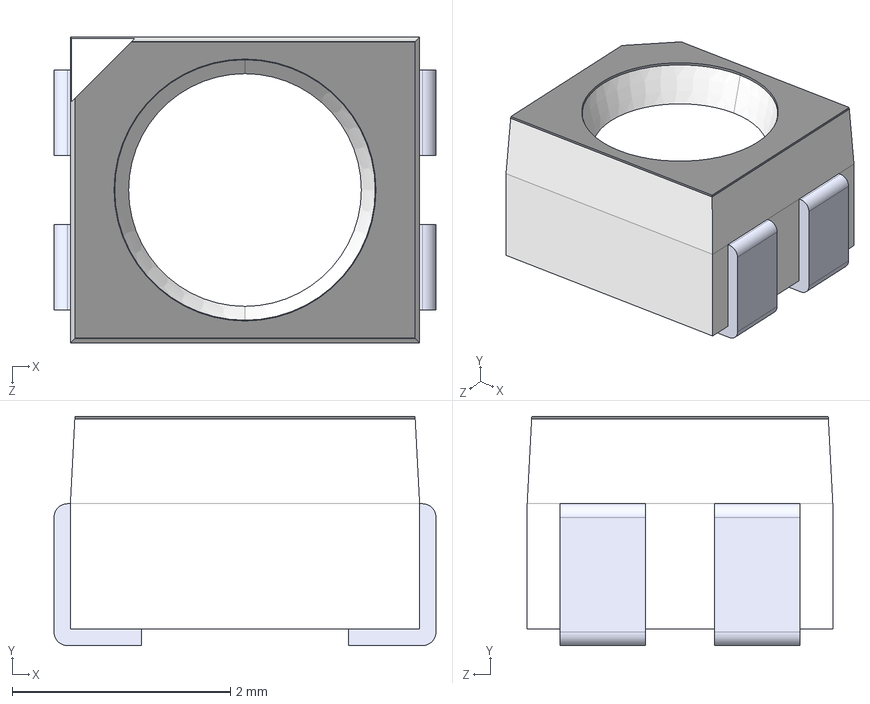
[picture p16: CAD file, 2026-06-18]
Hardware/Bauteildesigndaten/Dioden/WL-SFTW_3528_PLCC4/WL-SFTW_3528_PLCC4.step
3.50 x 2.10 x 2.80 mm

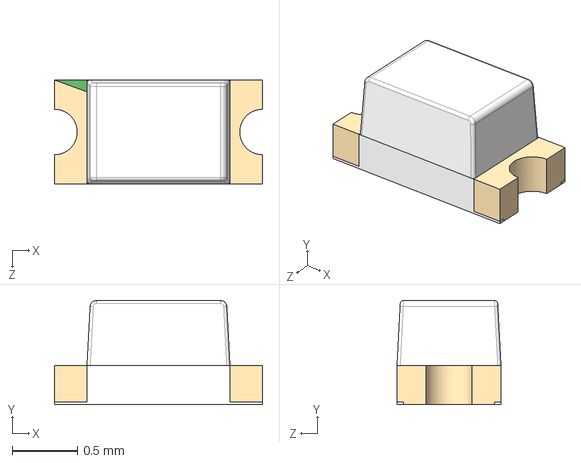
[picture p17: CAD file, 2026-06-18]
Hardware/Bauteildesigndaten/Dioden/WL-SMCW_0603_Green/WL-SMCW_0603_Green.step
1.60 x 0.8 x 0.8 mm

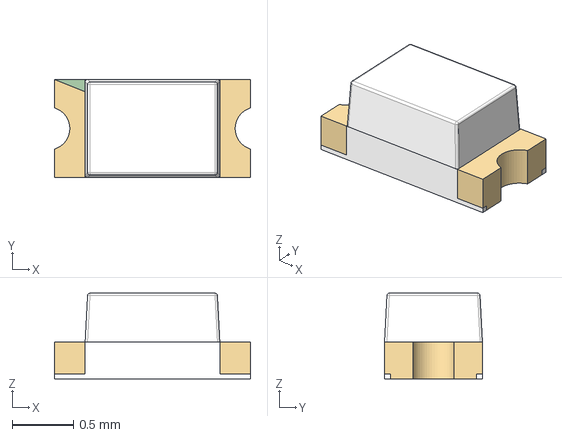
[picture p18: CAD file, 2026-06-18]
Hardware/Bauteildesigndaten/Dioden/WL-SMCW_0603_Yellow/WL-SMCW_0603_Yellow.step
1.60 x 0.8 x 0.7 mm

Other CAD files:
Hardware/Bauteildesigndaten/0ZCM0005FF2G/0ZCM0005FF2G.step
Hardware/Bauteildesigndaten/DMP3130L-7/DMP3130L-7.step
Hardware/Bauteildesigndaten/436331045822/436331045822+%28rev1%29.stp
Hardware/Bauteildesigndaten/61201421621/61201621621+%28rev1%29.stp
Hardware/Bauteildesigndaten/INA168QDBVRQ1/INA168QDBVRQ1.step
Hardware/Bauteildesigndaten/IRF9358PBF/IRF9358PBF.step
Hardware/Bauteildesigndaten/IRF9358TRPBF/IRF9358TRPBF.step
Hardware/Bauteildesigndaten/ISO7421D/ISO7421D.step
Hardware/Bauteildesigndaten/Importierte Bauteile/Buchsen/1861933/3D/172581824-659-1861933/1861933.stp
Hardware/Bauteildesigndaten/Importierte Bauteile/Buchsen/1933202/3D/172576339-659-1933202/1933202.stp
Hardware/Bauteildesigndaten/Importierte Bauteile/Buchsen/6120XX21621_61200821621/6120XX21621_61200821621.step
Hardware/Bauteildesigndaten/Importierte Bauteile/Buchsen/6120XX21621_61201021621/6120XX21621_61201021621.step
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

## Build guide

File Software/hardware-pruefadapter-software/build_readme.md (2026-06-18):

# Einrichtung der Build-Umgebung (WSL2 & PlatformIO)

Diese Anleitung beschreibt die Einrichtung der Toolchain unter Windows 11 mittels WSL2 (Windows Subsystem for Linux). Da WSL2 standardmäßig keine USB-Geräte erkennt, nutzen wir `usbipd-win`, um den ESP32 an die Linux-Umgebung durchzureichen. 
Ziel ist es, das Projekt am Ende nahtlos mittels `make` und `platformio` kompilieren, flashen und überwachen zu können.

---

## 1. WSL2 installieren (Windows Seite)

Falls noch kein Linux-Subsystem installiert ist:

1. Öffne die **PowerShell** als Administrator.
2. Führe folgenden Befehl aus:
   ```powershell
   wsl --install
   ```

3. Starte den Computer neu.
4. Nach dem Neustart öffnet sich ein Terminal. Richte dort deinen Linux-Benutzernamen und dein Passwort ein (Standardmäßig wird Ubuntu installiert).

---

## 2. USB-Unterstützung für WSL2 einrichten (`usbipd-win`)

Damit das Linux-System den per USB angeschlossenen ESP32 (COM-Port) sehen und flashen kann, muss geprüft werden ob das Open-Source-Tool namens `usbipd-win` auf Windows installiert ist.
```powershell
PS C:\Users\USERNAME> usbipd
Required command was not provided.

usbipd-win 5.3.0

Description:
  Shares locally connected USB devices to other machines, including Hyper-V guests and WSL 2.

Usage:
  usbipd [command] [options]

Options:
  -?, -h, --help  Show help and usage information
  --version       Show version information

Commands:
  attach   Attach a USB device to a client
  bind     Bind device
  detach   Detach a USB device from a client
  license  Display license information
  list     List USB devices
  policy   Manage policy rules
  server   Run the server on the console
  state    Output state in JSON
  unbind   Unbind device
```

### 2.2 ESP32 an WSL durchreichen

Schließe nun den ESP32 per USB an deinen Windows-PC an.

1. Öffne die **PowerShell als Administrator**!
2. Liste alle angeschlossenen USB-Geräte auf:
```powershell
usbipd list
```

*Suche in der Liste nach dem ESP32 (oft als "USB JTAG/serial debug unit" oder "CP210x" gelistet). Merke dir die Hardware-ID, meistens ist das beim ESP32-S3 `303a:1001`.*

3. **Gerät für Sharing binden** (Muss nur beim allerersten Mal pro Gerät gemacht werden):
```powershell
usbipd bind --hardware-id 303a:1001
```
*(Ersetze `303a:1001` falls dein ESP32 eine andere ID hat).*

4. **Gerät an WSL anhängen (Attach)**:
Öffne parallel dein Linux-Terminal (z.B. Ubuntu) im Hintergrund. Führe dann in der **Admin-PowerShell** aus:
```powershell
usbipd attach --wsl --hardware-id 303a:1001
```

> **Wichtig:** Schritt 4 (`attach`) musst du jedes Mal wiederholen, wenn du den ESP32 vom USB-Kabel trennst und wieder einsteckst, ein Reset gemacht wird oder WSL neu startest!

## 3. Toolchain installieren (Linux Seite)

Öffne nun dein WSL-Terminal (z.B. "Ubuntu" im Startmenü). Um sicherzugehen, dass der ESP32 erkannt wird, kannst du `lsusb` eingeben. Der ESP32 sollte nun in der Liste auftauchen.

### Schritt 3.1: Systempakete vorbereiten

Aktualisiere die Paketquellen und installiere die für USB und Python benötigten Grundpakete:

```bash
sudo apt update && sudo apt install python3-venv linux-tools-virtual hwdata curl
```

### Schritt 3.2: PlatformIO Core über das Installer-Skript installieren

PlatformIO empfiehlt offiziell die Nutzung des eigenen Installer-Skripts. Dieses richtet PlatformIO sicher in einer komplett isolierten, virtuellen Python-Umgebung ein.

1. Lade das Skript herunter:
```bash
curl -fsSL -o get-platformio.py [https://raw.githubusercontent.com/platformio/platformio-core-installer/master/get-platformio.py](https://raw.githubusercontent.com/platformio/platformio-core-installer/master/get-platformio.py)
```

2. Führe das Skript aus:
```bash
python3 get-platformio.py
```

### Schritt 3.3: Pfad-Konfiguration (Shell Commands)

Damit der Befehl `pio` im Terminal global verfügbar ist, muss das neu erstellte Verzeichnis zur Systemvariablen `PATH` hinzugefügt werden.

Führe folgenden Befehl aus, um PlatformIO zu deiner `~/.bashrc` hinzuzufügen:

```bash
echo 'export PATH="$PATH:$HOME/.platformio/penv/bin"' >> ~/.bashrc
```

Lade die Konfiguration danach neu:

```bash
source ~/.bashrc
```

### Schritt 3.4: Installation verifizieren

Prüfe, ob PlatformIO korrekt erkannt wird:

```bash
pio --version
```

Erwartete Ausgabe: `PlatformIO Core, version x.x.x`

---

## 4. Projekt kompilieren und flashen

Navigiere in deinem WSL-Terminal in das Verzeichnis dieses Projekts (wo das `Makefile` liegt). Du bist nun bereit, die Firmware zu bauen.

Das Projekt enthält ein `Makefile`, das die PlatformIO-Befehle abstrahiert. Nutze folgende Befehle:

| Befehl | Beschreibung |
| --- | --- |
| `make build` / `make` | Kompiliert die Firmware (`firmware.bin`) für den ESP32, ohne zu flashen. |
| `make flash` | Kompiliert und flasht die Firmware auf den ESP32. Setzt voraus, dass `usbipd attach` ausgeführt wurde! |
| `make monitor` | Startet den seriellen Monitor (Standardmäßig 115200 Baud). Beenden mit `Strg + C`. |
| `make clean` | Löscht alle temporären Build-Dateien (.pio Ordner). |
| `make native` | Baut das Projekt als PC-Simulation (ohne ESP32) und führt es direkt unter Linux aus. |
| `make test` | Führt die Unit-Tests des Projekts aus und speichert die Ergebnisse in `test_output.txt`. |

> **Troubleshooting Berechtigungen (Linux):**
> Sollte WSL beim Flashen Probleme mit Zugriffsrechten auf den USB-Port (`/dev/ttyACM0` oder `/dev/ttyUSB0`) haben, füge deinen Linux-User der `dialout`-Gruppe hinzu:
> `sudo usermod -aG dialout $USER`
> *(Danach das WSL-Terminal einmal komplett schließen und neu öffnen).*

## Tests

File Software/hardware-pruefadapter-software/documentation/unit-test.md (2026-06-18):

| ID | Datei | Service Name | Test Nr. & Name | Eingabe / Auslöser | Sollzustand / Verhalten | AAA-Muster | Edge Cases | Bemerkung |
| :--- | :--- | :--- | :--- | :--- | :--- | :--- | :--- | :--- |
| #001 | test_logic_api_controller.cpp | ApiController | 1; RoutesAreSuccessfullyRegistered | Start des Webservers. | Alle definierten GET, PUT und SSE Routen sind im Webserver Interface registriert. | Arrange: Mocks init. Act: Routen registrieren. Assert: Prüfen ob Routen im Fake-Server gemappt sind. | - | Prüft die korrekte Bindung der Endpunkte an den Webserver. |
| #002 | | ApiController | 2; GetIoAllReturnsCorrectJsonSchema | GET Request auf /api/v1/io. | Die Rückgabe enthält JSON-Arrays in der durch config::kNumChannels definierten Länge. | Arrange: Server aktiv. Act: GET Aufruf. Assert: JSON Struktur und Array-Größen validiert. | - | Stellt sicher, dass das Prozessabbild vollständig als JSON übertragen wird. |
| #003 | | ApiController | 3; PutAnalogOutputValidValueSucceeds | PUT Request auf analogen Ausgang mit gültigem Wert. | Der Wert wird in die Mailbox geschrieben. SystemController übernimmt Wert im nächsten Zyklus. | Arrange: Controller Start. Act: PUT Aufruf. Assert: JSON success und DAC Schreib-Aufruf geprüft nach Grace Period. | #004, #005 | Prüft die asynchrone Befehlsübergabe über die Mailbox. |
| #004 | | ApiController | 4; PutAnalogOutputExceedsMaximumFails | PUT Request mit Spannungswert über config-Limit. | API lehnt ab und meldet JSON-Fehler ("exceeds maximum"). | Arrange: Controller Start. Act: PUT Aufruf. Assert: Fehlermeldung in JSON Antwort verifiziert. | - | Testet die Out-of-Bounds Schutzschicht der API. |
| #005 | | ApiController | 5; PutWithInvalidJsonFailsGracefully | PUT Request mit syntaktisch falschem JSON-String. | API fängt Fehler ab, stürzt nicht ab und meldet JSON-Syntaxfehler. | Act: Sende defektes JSON. Assert: Rückgabe enthält entsprechenden Fehlerstring. | - | Schützt das System vor Abstürzen durch defekte JSON-Parser-Eingaben. |
| #006 | | ApiController | 6; PutDigitalOutputValidValueSucceeds | PUT Request auf digitalen Ausgangskanal mit booleschem Wert. | API meldet "success". Mailbox speichert Zustand für den Hardware-Zyklus. | Act: PUT Aufruf mit state:true. Assert: "success" Status in der Antwort. | - | Prüft die korrekte Verarbeitung boolescher API-Eingaben. |
| #007 | | ApiController | 7; PutDigitalReferenceChangesSystemConfig | PUT Request zur Änderung der digitalen Referenzspannung. | API ändert Systemkonfiguration im ProcessImager. Auswertung digitaler Signale passt sich an. | Arrange: 5V Ref setzen, 4.5V Input. Act: Zyklus. Assert: Zustand wird als HIGH berechnet. | - | Sichert die dynamische Laufzeitkonfiguration der Logikschwellen. |
| #008 | | ApiController | 8; PutSerialTxSendsDataToCorrectUart | PUT Request für seriellen Datenversand. | API schreibt Text in Mailbox. Daten werden im nächsten Hardware-Zyklus auf gewähltem UART ausgegeben. | Arrange: Mock für WriteBlock. Act: PUT Aufruf. Assert: WriteBlock des Treibers aufgerufen. | - | Verifiziert die Weiterleitung von UART-Befehlen an den Hardware-Puffer. |
| #009 | test_logic_system_controller.cpp | SystemController | 1; InitializationSucceedsWithValidHardware | Aufruf von Initialize bei intakter Hardware. | System meldet kSuccess. Alle Treiber werden mit konfigurierten Adressen und Werten gestartet. | Arrange: Mocks auf kSuccess. Act: Initialize. Assert: kSuccess Rückgabe. | #010, #011, #012 | Bestätigt den fehlerfreien Systemstart bei intakter Hardware. |
| #010 | | SystemController | 2; InitializationFailsWhenPointerIsNullAdc | Nullpointer für ADC Treiber im SystemContext übergeben. | ErrorManager registriert Nullpointer-Fehler. Initialisierung schließt mit kErrorInitWarning ab. | Arrange: ADC-Pointer null. Act: Initialize. Assert: Warnung zurückgegeben. | - | Verhindert Systemabstürze bei unvollständiger ADC-Treiber-Injektion. |
| #011 | | SystemController | 3; InitializationFailsWhenPointerIsNullDac | Nullpointer für DAC Treiber im SystemContext übergeben. | Warnung generiert. ErrorManager protokolliert das fehlende Interface. | Arrange: DAC-Pointer null. Act: Initialize. Assert: Warnung zurückgegeben. | - | Verhindert Systemabstürze bei unvollständiger DAC-Treiber-Injektion. |
| #012 | | SystemController | 4; InitializationFailsWhenPointerIsNullLed | Nullpointer für LED Treiber im SystemContext übergeben. | Warnung generiert. ErrorManager protokolliert das fehlende Interface. | Arrange: LED-Pointer null. Act: Initialize. Assert: Warnung zurückgegeben. | - | Verhindert Systemabstürze bei fehlender LED-Treiber-Injektion. |
| #013 | | SystemController | 5; AnalogOutputTargetIsProcessedAndSentToDac | Analoger Zielwert liegt in Mailbox vor. | Zielwert wird in Prozessabbild kopiert und per I2C an den DAC gesendet. | Arrange: Mocks init. Act: Wert in Mailbox, Zyklus. Assert: Wertauslesen liefert Zielwert. | - | Verifiziert den zentralen EVA-Zyklus für unregulierte Analog-Ausgaben. |
| #014 | | SystemController | 6; HardwareErrorIsLoggedProperly | I2C Lesefehler tritt während der Laufzeit auf. | Fehler wird erkannt und über den ErrorManager mit genauem Kontext protokolliert. | Arrange: ADC liefert Fehler. Act: Zyklus. Assert: Fehler-Array enthält I2C Meldung. | #027 | Sichert das korrekte Fehler-Tracing und Logging bei I2C-Ausfällen. |
| #015 | | SystemController | 7; DigitalInputThresholdRule | Analog-gewandelte Spannung fällt unter 20% der Referenz. | Controller wertet Zustand sicher als LOW (0) aus. | Arrange: Ref 24V, ADC 4V. Act: Zyklen. Assert: DigitalState = 0. | #017 | Bestätigt die normgerechte SPS-LOW-Auswertung. |
| #016 | | SystemController | 8; DigitalInputThresholdRuleHigh | Analog-gewandelte Spannung steigt über 80% der Referenz. | Controller wertet Zustand sicher als HIGH (1) aus. | Arrange: Ref 5V, ADC 4.5V. Act: Zyklen. Assert: DigitalState = 1. | #017 | Bestätigt die normgerechte SPS-HIGH-Auswertung. |
| #017 | | SystemController | 9; DigitalInputThresholdRuleFloat | Analog-gewandelte Spannung liegt zwischen 20% und 80%. | Controller wertet Zustand als ungültigen Graubereich bzw. FLOAT (-1) aus. | Arrange: Ref 24V, ADC 12V. Act: Zyklen. Assert: DigitalState = -1. | - | Fängt Kabelbrüche durch Detektion des undefinierten Graubereichs ab. |
| #018 | | SystemController | 10; AnalogInputMovingAverageFiltersNoise | Ein massiver Spannungspike (EMV) tritt auf. | Spike wird durch den gleitenden Mittelwert geglättet und schlägt nicht sofort durch. | Arrange: Puffer 5V, Spike 15V. Act: Zyklus. Assert: Prozessabbild zeigt gedämpften Wert. | - | Testet den Software-Tiefpassfilter gegen EMV-Spannungsspitzen. |
| #019 | | SystemController | 11; ErrorAutoRecoveryWorks | Ein temporärer Hardwarefehler verschwindet wieder. | Fehler wird im Folgezyklus vom ErrorManager selbstständig gelöscht (Auto-Recovery). | Arrange: ADC Fehler, dann kSuccess. Act: Zyklen. Assert: ErrorCount fällt auf 0. | - | Prüft die Auto-Heilung des Systems nach temporären I2C-Wackelkontakten. |
| #020 | | SystemController | 12; AnalogOutputReadbackIsProcessedCorrectly | Signal liegt auf dem Readback-ADC an. | Messwert wird in den reverse_voltage_check Puffer im Imager geschrieben. | Arrange: ADC 11.5V. Act: Zyklen. Assert: Readback liefert 11.5V. | - | Stellt sicher, dass physikalische Readback-Werte bereitstehen. |
| #021 | | SystemController | 13; SerialRxBuffersAndTriggersCallback | 5 Bytes empfangen, RX-Timeout Schwelle erreicht. | Daten werden bis zum Timeout gepuffert und gebündelt als Event weitergereicht. | Arrange: UART liefert 5 Bytes. Act: Warten > Timeout, Zyklus. Assert: Callback ausgelöst. | - | Bündelt serielle Netzwerk-Events zur Reduzierung der Systemlast. |
| #022 | | SystemController | 14; ReadAdcInputs_ValidDataIsMappedCorrectly | ADC misst valide Eingangsspannungen. | Werte werden kanalgenau den Input- und Readback-Registern im Imager zugewiesen. | Arrange: ADC 5V. Act: Zyklen. Assert: Input und Readback zeigen 5V. | #023 | Sichert das korrekte Mapping der Sensordaten in das Prozessabbild. |
| #023 | | SystemController | 15; ReadAdcInputs_I2cErrorResetsFilterAndValue | I2C Ausfall beim Auslesen eines ADCs. | Der Wert des Kanals wird genullt, der Mittelwert-Filter wird resettet. | Arrange: ADC Lesefehler. Act: Zyklus. Assert: Kanalwert = 0, Fehler geloggt. | - | Zwingt defekte analoge Kanäle aus Sicherheitsgründen auf 0V. |
| #024 | | SystemController | 16; ProcessSequence_CheckAndRegulateAnalogOut_RegulatesVoltage | Readback Spannung weicht vom Sollwert ab (innerhalb Toleranz). | Hybrid-Logik: P-Regler greift ein und berechnet Dynamisch den minimalen Sicherheits-Abstand zum Kurzschluss-Schutz. | Arrange: Dyn. Testwerte. Act: Schonfrist Zyklen. Assert: DAC wird reguliert. | #025 | Prüft die intelligente Hybrid-Logik (Software-Nachregelung ohne Fehlauslösung des Kurzschlussschutzes). |
| #025 | | SystemController | 17; ProcessSequence_CheckAndRegulateAnalogOut_ShortCircuitProtection | Readback zeigt > 10% Spannungsabfall zum Sollwert. | Kurzschlussverdacht: Nach Ablauf der Schonfrist wird DAC hart auf 0V gesetzt. | Arrange: Soll 12V, Ist 0V. Act: Schonfrist + 5 Zyklen. Assert: Sollspannung wird 0. | - | Schützt Bauteile durch Hardware-Notabschaltung bei Überlast/Kurzschluss. |
| #026 | | SystemController | 18; ProcessSequence_CheckDigitalOutSafety_DetectsVoltageDrop | Readback-Spannung eines aktivierten Digital-Outs bricht ein. | Sicherheitsabschaltung greift. Ausgang wird ausgeschaltet (LOW). | Arrange: Ref 24V, Readback 5V. Act: Schonfrist Zyklen. Assert: Kanal wird 0. | - | Sichert die korrekte Reaktion bei Einbruch der SPS-Versorgungsspannung. |
| #027 | | SystemController | 19; OutputSequence_UpdateDacOutputs_FailSafeOnHardwareError | Fehler beim Schreiben auf den I2C DAC. | Hardware-Fail-Safe: Analoger Fallback-GPIO des Kanals wird hart auf LOW gezogen. | Arrange: DAC.SetValue = Error. Act: Zyklus. Assert: GPIO LOW, Imager genullt. | - | Bietet redundante Hardware-Abschaltung über GPIO bei I2C-Verlust. |
| #028 | | SystemController | 20; OutputSequence_UpdateHardwareLeds_FloatStateIsRed | Eingang liefert FLOAT Zustand (-1). | RGB-Status-LED wird dynamisch über `kLedMap` ermittelt und zwingend auf ROT geschaltet. | Arrange: Ref Max, Input 50%. Act: Zyklus. Assert: LED Treiber Befehl Rot. | - | Gibt dem Anwender visuelles Feedback bei unklaren Zuständen. Dynamisches Routing gesichert. |
| #029 | | SystemController | 21; OutputSequence_UpdateSystemLed_ReactsToErrors | Ein beliebiger Fehler tritt auf. | Globale System-Status-LED wechselt auf Rot (Fehler). | Arrange: ADC Fehler erzwingen. Act: Zyklen. Assert: System-LED Rot angefordert. | - | Signalisiert globale Systemausfälle. |
| #030 | | SystemController | 22; ProcessSequence_CheckAndRegulateAnalogOut_CapsAtMaximumVoltage | Regler versucht über die Systemspannung (kMaxSystemVoltageMv) hinaus zu regeln. | Spannung wird vom P-Regler dynamisch hart auf das in der Config definierte Limit gekappt. | Arrange: DAC nahe am Max-Limit. Act: Zyklen. Assert: SetValue(kMaxSystemVoltageMv). | - | Verhindert Übersteuern der DAC Bausteine (No Magic Numbers). |
| #031 | | SystemController | 23; ProcessSequence_CheckAndRegulateAnalogOut_CapsAtMinimumVoltage | Regler versucht unter 0V zu regeln. | Spannung wird vom P-Regler hart auf das Minimum (0V) gekappt. | Arrange: DAC = 0.1V, Ziel = 0.1V, Ist = 2V. Act: Zyklen. Assert: SetValue(0). | - | Verhindert das Schreiben negativer Werte (Integer-Overflow) in DAC Register. |
| #032 | | SystemController | 24; ProcessSequence_CheckDigitalOutSafety_WaitsForGracePeriod | Digital Out wird gesetzt, ADC-Readback hinkt hinterher. | Safety-Check wartet die "Grace Period" ab, bevor er wegen Unterspannung abschaltet. | Arrange: Target = HIGH, ADC = 0V. Act: n Zyklen < Limit. Assert: Status bleibt HIGH. | - | Vermeidet Fehlalarme bei langsamen Messwandlern. |
| #033 | | SystemController | 25; ProcessSequence_CheckDigitalOutSafety_PassesIfHardwareSwitchesInTime | Readback erreicht die Schwelle noch innerhalb der Schonfrist. | Ausgang bleibt dauerhaft aktiv, kein Fehler wird geloggt. | Arrange: ADC liefert Max-Volts vor Fristablauf. Act: Limit-Zyklen. Assert: Kanal bleibt an. | - | Happy-Path der Digital-Out Überwachung. |
| #034 | test_service_error_manager.cpp | ErrorManager | 1; LogsNewErrorCorrectly | AddCycleError mit neuem Fehlercode aufgerufen. | Fehler wird im Schatten-Speicher geparkt und durch ResolveErrors übernommen. | Arrange: Manager clear. Act: Add, Resolve. Assert: Count=1, DTO korrekt. | - | Sichert das asynchrone Sammeln von Fehlern im Schatten-Speicher. |
| #035 | | ErrorManager | 2; AutoRecoversFromResolvedError | ResolveErrors wird gerufen, alter Fehler tritt nicht mehr auf. | Alter Fehler wird gelöscht, System gilt wieder als fehlerfrei (Count = 0). | Arrange: Fehler existent. Act: Clear, Resolve. Assert: ErrorCount=0. | - | Prüft das automatische Löschen von behobenen Fehlern. |
| #036 | | ErrorManager | 3; IgnoresDuplicateErrorsInSameCycle | Identischer Fehler wird zweimal im Zyklus gemeldet. | Fehler wird ignoriert und nur einmal im Schatten-Speicher abgelegt. | Arrange: Clear. Act: 2x gleicher Fehler, Resolve. Assert: ErrorCount=1. | - | Verhindert Log-Spamming durch Bündelung identischer Zyklus-Fehler. |
| #037 | | ErrorManager | 4; PreventsBufferOverflowOnMassiveFailures | Massive Anzahl von Hardwarefehlern (> kMaxCycleErrors). | Interner Puffer läuft nicht über. Überzählige Fehler werden verworfen. | Arrange: Clear. Act: > 30 Fehler melden, Resolve. Assert: Count kappt bei Limit. | - | Schützt den C++ RAM vor Overflow bei katastrophalen Kaskadenfehlern. |
| #038 | test_service_hardware_bootstrapper.cpp | HardwareBootstrapper | 1; BootFailsGracefullyOnNullptrs | Leerer SystemContext wird übergeben (Keine Treiber geladen). | Programm stürzt nicht ab. Nullpointer Einträge in ErrorManager, Boot "unhealthy". | Arrange: Context leer. Act: Boot. Assert: is_healthy=false, ErrorCount>0. | - | Fängt Software-Fehlkonfigurationen vor dem Start ab. |
| #039 | | HardwareBootstrapper | 2; BootSucceedsWithValidHardwareInfo | Vollständig besetzter SystemContext übergeben. | Hardware-Init-Bitmasken entsprechen der Config, Boot ist "healthy". | Arrange: Mocks in Context. Act: Boot. Assert: Masken matchen exakt den Konstanten. | #040 | Verifiziert die korrekten Startbedingungen und Bitmasken aller Treiber. |
| #040 | | HardwareBootstrapper | 3; BootRegistersHardwareErrors | I2C Init eines Chips schlägt fehl. | Start-Maske unvollständig. System startet im abgesicherten Modus ("unhealthy"). | Arrange: Ein ADC liefert Init-Fehler. Act: Boot. Assert: Maske weicht ab, ErrorCount>0. | - | Sichert den Fallback in den abgesicherten Modus bei Teil-Ausfällen. |
| #041 | test_service_led_manager.cpp | LedManager | 1; IgnoresUpdatesIfHealthMaskIsZero | Ausstehende LED-Updates für als defekt markierte Treiber (HealthMask = 0). | Der I2C-Schreibzugriff wird blockiert und der Befehl verworfen. | Arrange: Health=0. Act: Change-Flag setzen, UpdateHardwareLeds. Assert: Mock blockiert Aufruf. | - | Verhindert Abstürze durch Zugriffe auf nicht initialisierte Treiber. |
| #042 | | LedManager | 2; SetsCorrectColorsForDigitalIo | Prozessabbild signalisiert digitalen HIGH Zustand. | Der LED-Treiber wird angewiesen, dynamisch mappend die Farbe Grün (Status OK) zu setzen. | Arrange: Ref 24V, Input 24V. Act: UpdateHardwareLeds. Assert: SetColor(kGreen) aufgerufen. | - | Prüft die reguläre Zuweisung von Status-Farben via dynamischem Treiber-Mapping. |
| #043 | | LedManager | 3; SetsRedColorOnFloatState | Prozessabbild signalisiert undefinierten FLOAT Zustand (Graubereich). | Die physikalische Warn-LED für den Kanal wird zwingend auf Rot geschaltet. | Arrange: Ref 24V, Input 12V. Act: UpdateHardwareLeds. Assert: SetColor(kRed) aufgerufen. | - | Gibt visuelles Feedback bei Leitungsbruch oder Wackelkontakt. |
| #044 | | LedManager | 4; UpdatesSystemLedBasedOnErrorCount | System-LED Update wird mit und ohne aktive Systemfehler getriggert. | Die LED leuchtet Grün im Normalbetrieb und wechselt auf Rot, sobald ErrorCount > 0. | Arrange: System ohne/mit Fehler. Act: UpdateSystemLed. Assert: SetColor Grün bzw. Rot. | - | Koppelt den ErrorManager an die globale Hardware-Status-LED. |
| #045 | | LedManager | 5; LogsErrorIfI2cCommunicationFails | I2C-Kommunikationsabbruch beim Setzen einer LED-Farbe. | Der Fehler wird abgefangen und sauber an den ErrorManager übergeben. | Arrange: SetColor schlägt fehl. Act: UpdateHardwareLeds. Assert: ErrorCount im Manager > 0. | - | Erkennt Hardwareausfälle von LED-Treibern zur Laufzeit. |
| #046 | test_service_mailbox.cpp | Mailbox | 1; AnalogTarget_ValidAndInvalidBounds | Setzen von Analogwerten (Valide und Out-Of-Bounds). | Nur valider Wert wird gepuffert. Werte über Limit ignoriert. | Arrange: Mailbox Objekt. Act: Setze verschiedene Werte. Assert: Nur gültiger Wert im Snapshot. | - | Blockiert illegale Spannungswerte direkt an der Schnittstelle. |
| #047 | | Mailbox | 2; DigitalTarget_IgnoresInvalidChannels | Digitaler Wert auf nicht existentem Kanal. | Befehl wird restlos verworfen, um Array-Überläufe zu verhindern. | Act: Setze Kanal (Limit + 1). Assert: Snapshot erhält keine Daten für diesen Kanal. | - | Verhindert Array-Überläufe durch Filterung ungültiger Kanäle. |
| #048 | | Mailbox | 3; AnalogTarget_LastWriteWins | Kanal wird mehrfach mit verschiedenen Zielen beschrieben. | Letzter Schreibvorgang überschreibt vorherige Werte gnadenlos. | Act: Setze 5V, danach 10V. Assert: Snapshot liefert ausschließlich 10V. | - | Sichert die Thread-Sicherheit durch Last-Write-Wins Überschreibung. |
| #049 | | Mailbox | 4; SerialTx_AppendsMultiplePayloads | Mehrere Serielle Nachrichten kommen fast zeitgleich. | Payload-Strings werden sauber miteinander verkettet. Puffer wird beim Auslesen geleert. | Act: Add "AT", Add "+RST". Assert: Snapshot liefert "AT+RST". Folge-Snapshot leer. | - | Verhindert Datenverlust durch Verkettung schneller aufeinanderfolgender Strings. |
| #050 | | Mailbox | 5; SerialConfig_IgnoresInvalidBaudrates | Unsinnige Baudrate angefordert. | Befehle mit Baudraten über kMaxSerialBaudRate werden blockiert. | Act: Setze Baudrate über Limit. Assert: Snapshot enthält keine Änderungsanforderung. | - | Schützt die UART-Register vor inkompatiblen Taktraten. |
| #051 | test_service_moving_average_filter.cpp | MovingAverageFilter | 1; CalculatesAverageCorrectly | Filter-Puffer wird mit 3 Werten gefüllt. | Durchschnitt wird exakt über die vorhandenen Werte berechnet. | Act: 1000, 2000, 3000 addieren. Assert: Durchschnitt ist exakt 2000. | - | Prüft die korrekte mathematische Durchschnittsberechnung. |
| #052 | | MovingAverageFilter | 2; RingBufferOverridesOldestValues | Filter erhält mehr Werte, als Kapazität zulässt. | Älteste Messwerte werden verworfen und überschrieben (Ringpuffer Prinzip). | Arrange: Puffer voll mit 0V. Act: 10000V hinzu. Assert: Durchschnitt steigt an. | - | Verifiziert die FIFO-Ringpuffer-Logik beim Überschreiben alter Werte. |
| #053 | | MovingAverageFilter | 3; ResetClearsBufferAndPreventsDivByZero | Reset-Befehl bei gefülltem Filter ausgeführt. | Interner Zähler auf 0. GetAverage liefert 0 (Keine Division durch Null). | Act: Addieren, Reset, GetAverage. Assert: Rückgabe ist 0. | - | Verhindert Applikations-Abstürze durch Division durch Null. |
| #054 | test_service_process_imager.cpp | ProcessImager | 1; SyncUpdateToActive_TriggersChangeFlags | Sync-Befehl von temporären in aktive Arrays gerufen. | Wertänderungen werden detektiert. Change-Flags (Bitmasken) werden gesetzt. | Act: UpdateVoltage setzen, Sync. Assert: Masken-Bit ist 1. Zweiter Sync -> Bit ist 0. | - | Detektiert Flankenwechsel für eventbasierte Hardware-Updates. |
| #055 | | ProcessImager | 2; SafeGetters_ReturnZeroOnInvalidChannels | Lese-Zugriff auf Kanal über config-Limit. | Gibt 0 bzw. -1 zurück, illegaler Speicherzugriff wird unterbunden. | Act: Lese Channel über Limit. Assert: Wert ist 0. | - | Fängt illegale Lesezugriffe ab und verhindert Speicherverletzungen. |
| #056 | | ProcessImager | 3; SetDigitalReference_IgnoresInvalidInputs | Referenzspannung mit Parameter über Systemlimit (z.B. >24V). | Versuch wird blockiert. Referenzspannung verbleibt auf vorherigem Zustand. | Act: Setze Spannung über Limit. Assert: GetDigitalReference liefert Vorgabewert. | - | Schützt die Systemlogik vor fehlerhaften Referenzspannungswerten. |
| #057 | | ProcessImager | 4; GetDigitalState_CalculatesStatesCorrectly | Digitale Eingangsspannung soll ausgewertet werden. | Logik berechnet HIGH, LOW oder FLOAT relativ zur gesetzten Referenzspannung. | Act: Referenz 10V. Einspeisen von 9V, 1V, 5V. Assert: Liefert HIGH, LOW, FLOAT. | - | Bestätigt die dynamische Berechnung digitaler Zustände. |
| #058 | | ProcessImager | 5; AdjustedDacVoltage_StoresAndLimitsValues | Speichern der ausgeregelten DAC Zielspannung. | Wert wird gespeichert; fehlerhafte Eingaben über das Spannungslimit werden ignoriert. | Arrange: Setze > Limit. Act: GetAdjusted. Assert: Liefert Fallback (0V). | - | Prüft die Persistenz der geregelten Output-Schleife. |
| #059 | | ProcessImager | 6; Setters_IgnoreInvalidInputs | Diverse Setter (SetVoltage, SetUpdateVoltage etc) mit ungültigen Parametern. | Werteausreißer (Kanal, Enum) werden durch Bounds-Checks ignoriert. | Act: Rufe Setter mit ungültigen Enums. Assert: Get liefert keine Änderungen. | - | Verhindert Korruption des Prozessabbilds. |
| #060 | test_service_serial_streamer.cpp | SerialStreamer | 1; WriteTx_IgnoredIfHealthMaskIsZero | Schreibbefehl an als "defekt" gemeldeten Port. | Treiber schlug beim Booten fehl (HealthMask = 0). Service blockt Zugriff ab. | Arrange: Health=0. Act: WriteTx. Assert: Kein Aufruf im Mock-Treiber. | #061 | Blockiert Schreibbefehle an inaktive oder defekte Schnittstellen. |
| #061 | | SerialStreamer | 2; WriteTx_CalledIfPortIsHealthy | Schreibbefehl an intakten Port. | Payload wird ungehindert an WriteBlock Methode des Hardware-Treibers geleitet. | Arrange: Health=1. Act: WriteTx. Assert: WriteBlock 1x aufgerufen. | - | Sichert die korrekte Weitergabe von Payloads an die UART-Treiber. |
| #062 | | SerialStreamer | 3; SetBaudrate_IgnoredForInvalidPorts | Änderung der Baudrate über Limit oder falscher Port-ID. | Befehl wird durch Bounds-Check vor dem Hardware-Zugriff gefiltert. | Arrange: Health=1. Act: Falscher Port, unsinnige Baud. Assert: Kein Aufruf auf Mock. | - | Verhindert fehlerhafte Konfigurationen durch Bounds-Checks. |
| #063 | | SerialStreamer | 4; ProcessReadRx_TriggersCallbackOnTimeout | Empfangene Bytes erreichen nicht Paketgröße, Timeout verstreicht. | Puffer-Fragmente werden durch Timeout als Gesamt-String an API übermittelt. | Arrange: 5 Bytes empfangen. Act: Warten > Timeout, ProcessReadRx. Assert: Callback feuert. | - | Optimiert die Netzwerklast durch zeitgesteuertes Puffern der RX-Daten. |
| #064 | test_service_web_bouncer.cpp | WebBouncer | 1; AcquireSlot_LimitsAtMaxClients | Anfragen erreichen das Konfigurations-Limit kWebServerMaxClients. | Die Methode akzeptiert Anfragen bis zum Limit und weist alle weiteren mit false ab. | Arrange: Reset. Act: Slots füllen. Assert: Rückgabe false ab Limit. | - | Prüft die feste Begrenzung der gleichzeitigen Verbindungen. |
| #065 | | WebBouncer | 2; ReleaseSlot_FreesSpaceForNewRequests | Ein blockierter Slot wird freigegeben. | Genau eine neue Anfrage wird wieder akzeptiert, die nachfolgende wird blockiert. | Arrange: Limit erreicht. Act: Release, Acquire. Assert: True, dann wieder false. | - | Sichert die kontinuierliche Annahme nach der Abarbeitung. |
| #066 | | WebBouncer | 3; ReleaseSlot_DoesNotUnderflow | Slot-Freigabe wird ohne aktive Anfragen aufgerufen. | Der interne Zähler geht nicht in den negativen Bereich (Underflow). Anfragen bleiben weiter möglich. | Arrange: Reset. Act: Release mehrfach aufrufen. Assert: Neues Acquire ist erfolgreich. | Underflow bei Zähler-Asynchronität. | Verhindert Puffer-Crashes bei asynchronen Server-Abbrüchen. |
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

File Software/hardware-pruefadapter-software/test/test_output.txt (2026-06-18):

================ ÜBERSICHT ================
Verbosity level can be increased via `-v, -vv, or -vvv` option
Collected 1 tests

Processing test_desktop in native environment
--------------------------------------------------------------------------------
Building...
Testing...
[02:25: ApiControllerTest.RoutesAreSuccessfullyRegistered: 30.770] ========== SIMULATION ==========	[PASSED]
[02:25: ApiControllerTest.GetIoAllReturnsCorrectJsonSchema: 30.770] ========== SIMULATION ==========	[PASSED]
[02:25: ApiControllerTest.PutAnalogOutputValidValueSucceeds: 30.771] ========== SIMULATION ==========	[PASSED]
[02:25: ApiControllerTest.PutAnalogOutputExceedsMaximumFails: 30.773] ========== SIMULATION ==========	[PASSED]
[02:25: ApiControllerTest.PutWithInvalidJsonFailsGracefully: 30.773] ========== SIMULATION ==========	[PASSED]
[02:25: ApiControllerTest.PutDigitalOutputValidValueSucceeds: 30.773] ========== SIMULATION ==========	[PASSED]
[02:25: ApiControllerTest.PutDigitalReferenceChangesSystemConfig: 30.773] ========== SIMULATION ==========	[PASSED]
[02:25: ApiControllerTest.PutSerialTxSendsDataToCorrectUart: 30.774] ========== SIMULATION ==========	[PASSED]
[02:25: SystemControllerTest.InitializationSucceedsWithValidHardware: 30.774] ========== SIMULATION ==========	[PASSED]
[02:25: SystemControllerTest.InitializationFailsWhenPointerIsNullAdc: 30.774] ========== SIMULATION ==========	[PASSED]
[02:25: SystemControllerTest.InitializationFailsWhenPointerIsNullDac: 30.775] ========== SIMULATION ==========	[PASSED]
[02:25: SystemControllerTest.InitializationFailsWhenPointerIsNullLed: 30.775] ========== SIMULATION ==========	[PASSED]
[02:25: SystemControllerTest.AnalogOutputTargetIsProcessedAndSentToDac: 30.775] ========== SIMULATION ==========	[PASSED]
[02:25: SystemControllerTest.HardwareErrorIsLoggedProperly: 30.775] ========== SIMULATION ==========	[PASSED]
[02:25: SystemControllerTest.DigitalInputThresholdRule: 30.775] ========== SIMULATION ==========	[PASSED]
[02:25: SystemControllerTest.DigitalInputThresholdRuleHigh: 30.776] ========== SIMULATION ==========	[PASSED]
[02:25: SystemControllerTest.DigitalInputThresholdRuleFloat: 30.777] ========== SIMULATION ==========	[PASSED]
[02:25: SystemControllerTest.AnalogInputMovingAverageFiltersNoise: 30.778] ========== SIMULATION ==========	[PASSED]
[02:25: SystemControllerTest.ErrorAutoRecoveryWorks: 30.780] ========== SIMULATION ==========	[PASSED]
[02:25: SystemControllerTest.AnalogOutputReadbackIsProcessedCorrectly: 30.780] ========== SIMULATION ==========	[PASSED]
[02:25: SystemControllerTest.SerialRxBuffersAndTriggersCallback: 30.782] ========== SIMULATION ==========	[PASSED]
[02:25: SystemControllerTest.ReadAdcInputs_ValidDataIsMappedCorrectly: 30.842] ========== SIMULATION ==========	[PASSED]
[02:25: SystemControllerTest.ReadAdcInputs_I2cErrorResetsFilterAndValue: 30.843] ========== SIMULATION ==========	[PASSED]
[02:25: SystemControllerTest.ProcessSequence_CheckAndRegulateAnalogOut_RegulatesVoltage: 30.844] ========== SIMULATION ==========	[PASSED]
[02:25: SystemControllerTest.ProcessSequence_CheckAndRegulateAnalogOut_ShortCircuitProtection: 30.847] ========== SIMULATION ==========	[PASSED]
[02:25: SystemControllerTest.ProcessSequence_CheckDigitalOutSafety_DetectsVoltageDrop: 30.849] ========== SIMULATION ==========	[PASSED]
[02:25: SystemControllerTest.OutputSequence_UpdateDacOutputs_FailSafeOnHardwareError: 30.852] ========== SIMULATION ==========	[PASSED]
[02:25: SystemControllerTest.OutputSequence_UpdateHardwareLeds_FloatStateIsRed: 30.853] ========== SIMULATION ==========	[PASSED]
[02:25: SystemControllerTest.OutputSequence_UpdateSystemLed_ReactsToErrors: 30.854] ========== SIMULATION ==========	[PASSED]
[02:25: SystemControllerTest.ProcessSequence_CheckAndRegulateAnalogOut_CapsAtMaximumVoltage: 30.854] ========== SIMULATION ==========	[PASSED]
[02:25: SystemControllerTest.ProcessSequence_CheckAndRegulateAnalogOut_CapsAtMinimumVoltage: 30.857] ========== SIMULATION ==========	[PASSED]
[02:25: SystemControllerTest.ProcessSequence_CheckDigitalOutSafety_WaitsForGracePeriod: 30.859] ========== SIMULATION ==========	[PASSED]
[02:25: SystemControllerTest.ProcessSequence_CheckDigitalOutSafety_PassesIfHardwareSwitchesInTime: 30.862] ========== SIMULATION ==========	[PASSED]
[02:25: ErrorManagerTest.LogsNewErrorCorrectly: 30.865] [WARN] [ADC 1] Device nicht gefunden oder antwortet nicht	[PASSED]
[02:25: ErrorManagerTest.AutoRecoversFromResolvedError: 30.865] [WARN] [I2C Bus 2] Allgemeines I2C Kommunikations Problem	[PASSED]
[02:25: ErrorManagerTest.IgnoresDuplicateErrorsInSameCycle: 30.865] [WARN] [I2C Bus 2] Allgemeines I2C Kommunikations Problem	[PASSED]
[02:25: ErrorManagerTest.PreventsBufferOverflowOnMassiveFailures: 30.865] [WARN] [Test 0] Wert außerhalb des Bereichs	[PASSED]
[02:25: HardwareBootstrapperTest.BootFailsGracefullyOnNullptrs: 30.865] [WARN] ADC Chip 1 fehlt im Context!	[PASSED]
[02:25: HardwareBootstrapperTest.BootSucceedsWithValidHardwareInfo: 30.865] [INFO] ADC Chip 1 im Context gefunden.	[PASSED]
[02:25: HardwareBootstrapperTest.BootRegistersHardwareErrors: 30.865] [INFO] ADC Chip 1 im Context gefunden.	[PASSED]
LedManagerTest.IgnoresUpdatesIfHealthMaskIsZero	[PASSED]
[02:25: LedManagerTest.SetsCorrectColorsForDigitalIo: 30.865] [INFO] [SYSTEM] Referenzspannung fuer Digital IN Kanal 1 auf 24000 mV gesetzt	[PASSED]
[02:25: LedManagerTest.SetsRedColorOnFloatState: 30.865] [INFO] [SYSTEM] Referenzspannung fuer Digital IN Kanal 2 auf 24000 mV gesetzt	[PASSED]
[02:25: LedManagerTest.UpdatesSystemLedBasedOnErrorCount: 30.865] [LED] Treiber 2 Ch 3 wurde auf Grün gesetzt.	[PASSED]
[02:25: LedManagerTest.LogsErrorIfI2cCommunicationFails: 30.865] [WARN] [LED-Treiber 0Ch 5 [SetColor]] Allgemeines I2C Kommunikations Problem	[PASSED]
[02:25: MailboxTest.AnalogTarget_ValidAndInvalidBounds: 30.865] [MAILBOX] Neuer Analog Wert für Kanal 1: 15.00 V empfangen.	[PASSED]
[02:25: MailboxTest.DigitalTarget_IgnoresInvalidChannels: 30.865] [MAILBOX] Neuer Digital Wert für Kanal 1: ON empfangen.	[PASSED]
[02:25: MailboxTest.AnalogTarget_LastWriteWins: 30.865] [MAILBOX] Neuer Analog Wert für Kanal 3: 5.00 V empfangen.	[PASSED]
MailboxTest.SerialTx_AppendsMultiplePayloads	[PASSED]
MailboxTest.SerialConfig_IgnoresInvalidBaudrates	[PASSED]
MovingAverageFilterTest.CalculatesAverageCorrectly	[PASSED]
MovingAverageFilterTest.RingBufferOverridesOldestValues	[PASSED]
MovingAverageFilterTest.ResetClearsBufferAndPreventsDivByZero	[PASSED]
[02:25: ProcessImagerTest.SyncUpdateToActive_TriggersChangeFlags: 30.865] [SYSTEM] Änderung am Prozessabbild erkannt: Bank: 2, Channel: 2, Neuer Wert: 5000 mV	[PASSED]
ProcessImagerTest.SafeGetters_ReturnZeroOnInvalidChannels	[PASSED]
[02:25: ProcessImagerTest.SetDigitalReference_IgnoresInvalidInputs: 30.865] [INFO] [SYSTEM] Referenzspannung fuer Digital IN Kanal 1 auf 5000 mV gesetzt	[PASSED]
[02:25: ProcessImagerTest.GetDigitalState_CalculatesStatesCorrectly: 30.865] [INFO] [SYSTEM] Referenzspannung fuer Digital IN Kanal 1 auf 10000 mV gesetzt	[PASSED]
ProcessImagerTest.AdjustedDacVoltage_StoresAndLimitsValues	[PASSED]
ProcessImagerTest.Setters_IgnoreInvalidInputs	[PASSED]
SerialStreamerTest.WriteTx_IgnoredIfHealthMaskIsZero	[PASSED]
SerialStreamerTest.WriteTx_CalledIfPortIsHealthy	[PASSED]
SerialStreamerTest.SetBaudrate_IgnoredForInvalidPorts	[PASSED]
SerialStreamerTest.ProcessReadRx_TriggersCallbackOnTimeout	[PASSED]
WebBouncerTest.AcquireSlot_LimitsAtMaxClients	[PASSED]
WebBouncerTest.ReleaseSlot_FreesSpaceForNewRequests	[PASSED]
WebBouncerTest.ReleaseSlot_DoesNotUnderflow	[PASSED]
WebBouncerTest.AllowSseConnection_LimitsMaxStreams	[PASSED]
DataConverterUtilsTest.EvaluatesSpsLogicCorrectly	[PASSED]
DataConverterUtilsTest.EvaluatesExactThresholdBoundaries	[PASSED]
DataConverterUtilsTest.DeterminesCorrectLedColor	[PASSED]
---------------- native:test_desktop [PASSED] Took 8.21 seconds ----------------

=================================== SUMMARY ===================================
Environment    Test          Status    Duration
-------------  ------------  --------  ------------
native         test_desktop  PASSED    00:00:08.206
================= 70 test cases: 70 succeeded in 00:00:08.206 =================

================ VERBOSE DETAILS ================
Collected 1 tests (test_desktop)

Processing test_desktop in native environment
--------------------------------------------------------------------------------
Building...

Testing...
[==========] Running 70 tests from 11 test suites.
[----------] Global test environment set-up.
[----------] 8 tests from ApiControllerTest
[ RUN      ] ApiControllerTest.RoutesAreSuccessfullyRegistered
[02:25:32.070] ========== SIMULATION ==========
[02:25:32.070] Platform: Native (WSL/Linux/Windows)
[02:25:32.070] C++ Standard: 201703
[02:25:32.070] ================================

[02:25:32.070] [INFO] ADC Chip 1 im Context gefunden.
[02:25:32.070] [INFO] ADC Chip 1 Initialisierung erfolgreich.
[02:25:32.070] [INFO] ADC Chip 2 im Context gefunden.
[02:25:32.070] [INFO] ADC Chip 2 Initialisierung erfolgreich.
[02:25:32.070] [INFO] ADC Chip 3 im Context gefunden.
[02:25:32.070] [INFO] ADC Chip 3 Initialisierung erfolgreich.
[02:25:32.070] [INFO] ADC Chip 4 im Context gefunden.
[02:25:32.070] [INFO] ADC Chip 4 Initialisierung erfolgreich.
[02:25:32.070] [INFO] DAC Digital-Out 1 im Context gefunden.
[02:25:32.070] [INFO] DAC 1 Initialisierung erfolgreich.
[02:25:32.070] [INFO] LED Driver 1 initialisiert.
[02:25:32.070] [INFO] LED Driver 2 initialisiert.
[02:25:32.070] [INFO] LED Driver 3 initialisiert.
[02:25:32.070] [INFO] Serial Interface UART im Context gefunden.
[02:25:32.070] [INFO] Serial Interface UART erfolgreich initialisiert.
[02:25:32.070] [INFO] Serial Interface RS485 im Context gefunden.
[02:25:32.070] [INFO] Serial Interface RS485 erfolgreich initialisiert.
[02:25:32.070] [INFO] Serial Interface RS232 im Context gefunden.
[02:25:32.070] [INFO] Serial Interface RS232 erfolgreich initialisiert.
[02:25:32.070] [SYSTEM] Initialisierung erfolgreich.

[02:25:32.070] [INFO] [LED] Alle LEDs wurden abgeschaltet.
[       OK ] ApiControllerTest.RoutesAreSuccessfullyRegistered (0 ms)
[ RUN      ] ApiControllerTest.GetIoAllReturnsCorrectJsonSchema
[02:25:32.071] ========== SIMULATION ==========
[02:25:32.071] Platform: Native (WSL/Linux/Windows)
[02:25:32.071] C++ Standard: 201703
[02:25:32.071] ================================

[02:25:32.071] [INFO] ADC Chip 1 im Context gefunden.
[02:25:32.071] [INFO] ADC Chip 1 Initialisierung erfolgreich.
[02:25:32.071] [INFO] ADC Chip 2 im Context gefunden.
[02:25:32.071] [INFO] ADC Chip 2 Initialisierung erfolgreich.
[02:25:32.071] [INFO] ADC Chip 3 im Context gefunden.
[02:25:32.071] [INFO] ADC Chip 3 Initialisierung erfolgreich.
[02:25:32.071] [INFO] ADC Chip 4 im Context gefunden.
[02:25:32.071] [INFO] ADC Chip 4 Initialisierung erfolgreich.
[02:25:32.071] [INFO] DAC Digital-Out 1 im Context gefunden.
[02:25:32.071] [INFO] DAC 1 Initialisierung erfolgreich.
[02:25:32.071] [INFO] LED Driver 1 initialisiert.
[02:25:32.071] [INFO] LED Driver 2 initialisiert.
[02:25:32.071] [INFO] LED Driver 3 initialisiert.
[02:25:32.071] [INFO] Serial Interface UART im Context gefunden.
[02:25:32.071] [INFO] Serial Interface UART erfolgreich initialisiert.
[02:25:32.071] [INFO] Serial Interface RS485 im Context gefunden.
[02:25:32.071] [INFO] Serial Interface RS485 erfolgreich initialisiert.
[02:25:32.071] [INFO] Serial Interface RS232 im Context gefunden.
[02:25:32.071] [INFO] Serial Interface RS232 erfolgreich initialisiert.
[02:25:32.071] [SYSTEM] Initialisierung erfolgreich.

[02:25:32.071] [INFO] [LED] Alle LEDs wurden abgeschaltet.
[       OK ] ApiControllerTest.GetIoAllReturnsCorrectJsonSchema (0 ms)
[ RUN      ] ApiControllerTest.PutAnalogOutputValidValueSucceeds
[02:25:32.071] ========== SIMULATION ==========
[02:25:32.071] Platform: Native (WSL/Linux/Windows)
[02:25:32.071] C++ Standard: 201703
[02:25:32.071] ================================

[02:25:32.071] [INFO] ADC Chip 1 im Context gefunden.
[02:25:32.071] [INFO] ADC Chip 1 Initialisierung erfolgreich.
[02:25:32.071] [INFO] ADC Chip 2 im Context gefunden.
[02:25:32.071] [INFO] ADC Chip 2 Initialisierung erfolgreich.
[02:25:32.071] [INFO] ADC Chip 3 im Context gefunden.
[02:25:32.071] [INFO] ADC Chip 3 Initialisierung erfolgreich.
[02:25:32.071] [INFO] ADC Chip 4 im Context gefunden.
[02:25:32.071] [INFO] ADC Chip 4 Initialisierung erfolgreich.
[02:25:32.071] [INFO] DAC Digital-Out 1 im Context gefunden.
[02:25:32.071] [INFO] DAC 1 Initialisierung erfolgreich.
[02:25:32.071] [INFO] LED Driver 1 initialisiert.
[02:25:32.071] [INFO] LED Driver 2 initialisiert.
[02:25:32.071] [INFO] LED Driver 3 initialisiert.
[02:25:32.071] [INFO] Serial Interface UART im Context gefunden.
[02:25:32.071] [INFO] Serial Interface UART erfolgreich initialisiert.
[02:25:32.071] [INFO] Serial Interface RS485 im Context gefunden.
[02:25:32.071] [INFO] Serial Interface RS485 erfolgreich initialisiert.
[02:25:32.071] [INFO] Serial Interface RS232 im Context gefunden.
[02:25:32.071] [INFO] Serial Interface RS232 erfolgreich initialisiert.
[02:25:32.071] [SYSTEM] Initialisierung erfolgreich.

[02:25:32.071] [INFO] [LED] Alle LEDs wurden abgeschaltet.
[02:25:32.071] [MAILBOX] Neuer Analog Wert für Kanal 1: 12.00 V empfangen.

[02:25:32.071] [SYSTEM] Änderung am Prozessabbild erkannt: Bank: 0, Channel: 0, Neuer Wert: 12000 mV
[02:25:32.071] [SYSTEM] Änderung am Prozessabbild erkannt: Bank: 0, Channel: 1, Neuer Wert: 12000 mV
[02:25:32.071] [SYSTEM] Änderung am Prozessabbild erkannt: Bank: 0, Channel: 2, Neuer Wert: 12000 mV
[02:25:32.071] [SYSTEM] Änderung am Prozessabbild erkannt: Bank: 0, Channel: 3, Neuer Wert: 12000 mV
[02:25:32.071] [SYSTEM] Änderung am Prozessabbild erkannt: Bank: 1, Channel: 0, Neuer Wert: 12000 mV
[02:25:32.071] [SYSTEM] Änderung am Prozessabbild erkannt: Bank: 1, Channel: 1, Neuer Wert: 12000 mV
[02:25:32.071] [SYSTEM] Änderung am Prozessabbild erkannt: Bank: 1, Channel: 2, Neuer Wert: 12000 mV
[02:25:32.071] [SYSTEM] Änderung am Prozessabbild erkannt: Bank: 1, Channel: 3, Neuer Wert: 12000 mV
[02:25:32.071] [SYSTEM] Änderung am Prozessabbild erkannt: Bank: 2, Channel: 0, Neuer Wert: 12000 mV
[02:25:32.071] [INFO] [DEBUG] Schreibe DAC Kanal 1 auf 2.40 V
[02:25:32.071] [LED] Treiber 2 Ch 3 wurde auf Grün gesetzt.
[       OK ] ApiControllerTest.PutAnalogOutputValidValueSucceeds (1 ms)
[ RUN      ] ApiControllerTest.PutAnalogOutputExceedsMaximumFails
[02:25:32.073] ========== SIMULATION ==========
[02:25:32.073] Platform: Native (WSL/Linux/Windows)
[02:25:32.073] C++ Standard: 201703
[02:25:32.073] ================================

[02:25:32.073] [INFO] ADC Chip 1 im Context gefunden.
[02:25:32.073] [INFO] ADC Chip 1 Initialisierung erfolgreich.
[02:25:32.073] [INFO] ADC Chip 2 im Context gefunden.
[02:25:32.073] [INFO] ADC Chip 2 Initialisierung erfolgreich.
[02:25:32.073] [INFO] ADC Chip 3 im Context gefunden.
[02:25:32.073] [INFO] ADC Chip 3 Initialisierung erfolgreich.
[02:25:32.073] [INFO] ADC Chip 4 im Context gefunden.
[02:25:32.073] [INFO] ADC Chip 4 Initialisierung erfolgreich.
[02:25:32.073] [INFO] DAC Digital-Out 1 im Context gefunden.
[02:25:32.073] [INFO] DAC 1 Initialisierung erfolgreich.
[02:25:32.073] [INFO] LED Driver 1 initialisiert.
[02:25:32.073] [INFO] LED Driver 2 initialisiert.
[02:25:32.073] [INFO] LED Driver 3 initialisiert.
[02:25:32.073] [INFO] Serial Interface UART im Context gefunden.
[02:25:32.073] [INFO] Serial Interface UART erfolgreich initialisiert.
[02:25:32.073] [INFO] Serial Interface RS485 im Context gefunden.
[02:25:32.073] [INFO] Serial Interface RS485 erfolgreich initialisiert.
[02:25:32.073] [INFO] Serial Interface RS232 im Context gefunden.
[02:25:32.073] [INFO] Serial Interface RS232 erfolgreich initialisiert.
[02:25:32.073] [SYSTEM] Initialisierung erfolgreich.
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

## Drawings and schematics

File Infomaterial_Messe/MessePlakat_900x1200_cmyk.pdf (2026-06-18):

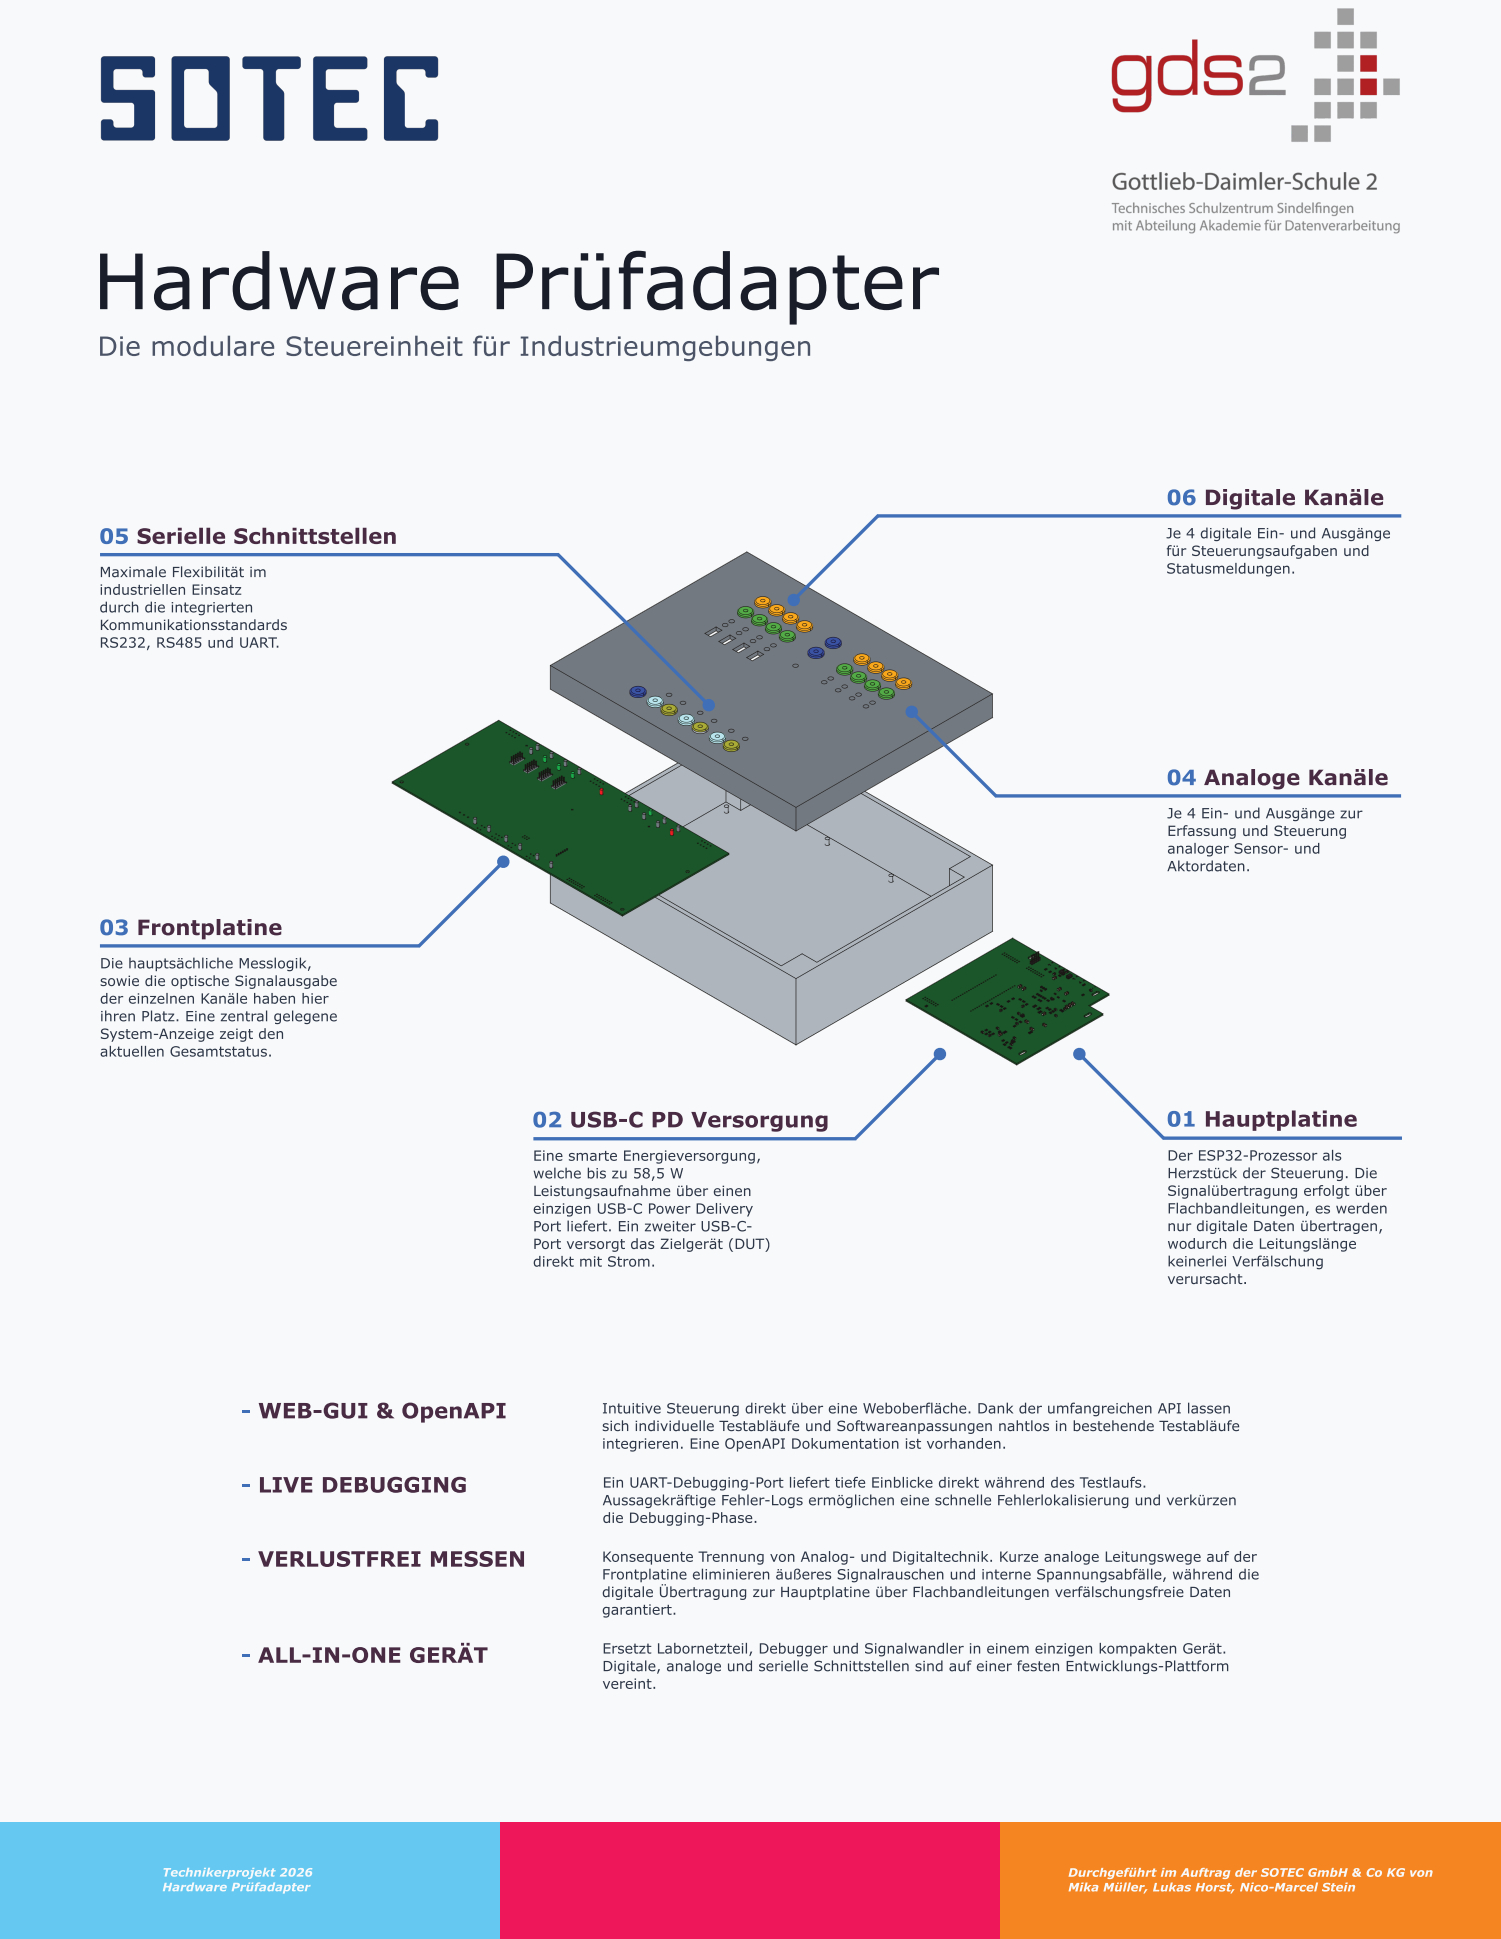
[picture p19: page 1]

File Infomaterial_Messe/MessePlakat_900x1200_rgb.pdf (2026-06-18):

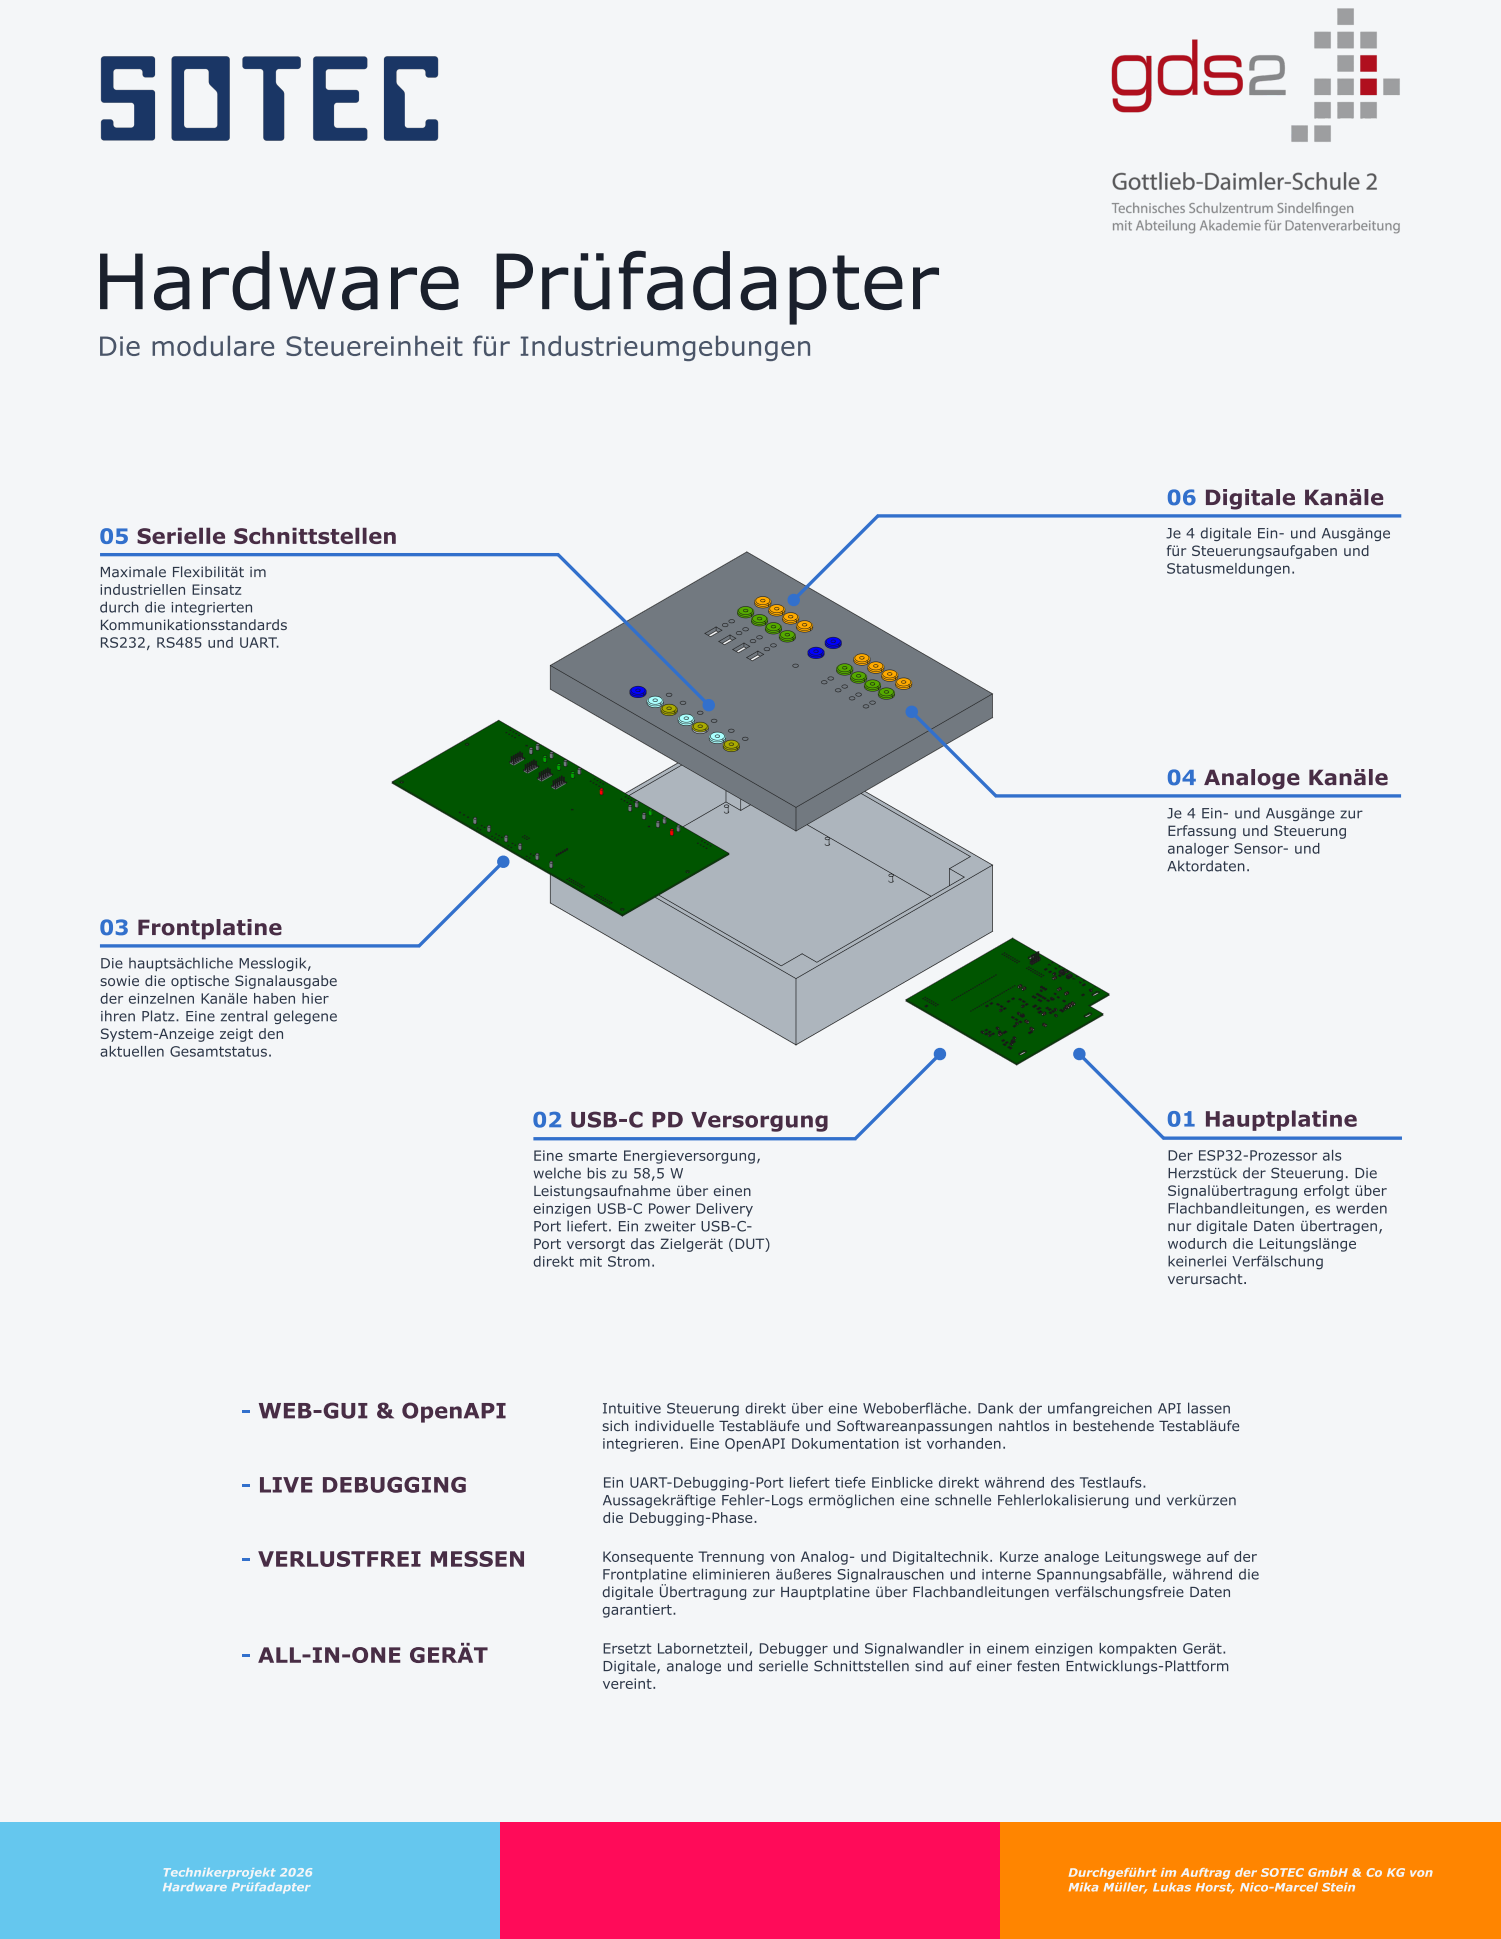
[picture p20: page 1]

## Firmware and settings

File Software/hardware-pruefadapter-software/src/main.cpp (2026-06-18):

/**
 * @file main.cpp
 * @brief Entry Point: Hier werden die Business-Logik und
 * Hardware-Initialisierung verknüpft.
 *
 * Architektur:
 * 1. Setup (Hardware & Software Komponenten instanziieren)
 * 2. Wiring (Abhängigkeiten injizieren via Constructor Injection)
 * 3. Loop (Zyklische Ausführung)
 */

#include <chrono>
#include <iostream>
#include <memory>
#include <thread>

// --- Core Logic ---
#include "ApiController/api_controller.h"
#include "SystemController/system_controller.h"
#include "system_config.h"
#include "system_context.h"
#include "system_types.h"

// --- Services ---
#include "../Logic/Services/error_manager.h"
#include "../Logic/Services/led_manager_service.h"
#include "../Logic/Services/mailbox_service.h"
#include "../Logic/Services/process_imager_service.h"
#include "../Logic/Services/serial_streamer.h"

// --- Utils ---
#include "../Logic/Utils/nonblocking_delay_utils.h"

// --- Interfaces ---
#include "../Interfaces/analog_to_digital_interface.h"
#include "../Interfaces/digital_to_analog_interface.h"
#include "../Interfaces/led_interface.h"
#include "../Interfaces/web_server_interface.h"

// --- Platform Abstraction ---
#include "platform_factory.h"

// Namespaces
namespace app = ::hardware_pruefadapter;

// =============================================================================
// ================================ LOGIC LAYER ================================
// =============================================================================

// --- Globale Instanzen ---
app::core::SystemContext sys_ctx;

std::unique_ptr<app::interfaces::IWebServer> web_server;
std::unique_ptr<app::core::SystemController> system_controller;
std::unique_ptr<app::logic::ApiController> api_controller;

// --- Serivce-Instanzen ---
std::unique_ptr<app::logic::ErrorManager> error_manager;
std::unique_ptr<app::logic::ProcessImager> process_imager;
std::unique_ptr<app::logic::Mailbox> mailbox;
std::unique_ptr<app::logic::SerialStreamer> serial_streamer;
std::unique_ptr<app::logic::LedManager> led_manager;

// --- Utility-Instanzen ---
app::utils::NonBlockingDelay loop_delay(1000);

// --- Hardware-Treiber ---
std::unique_ptr<app::interfaces::IAnalogToDigitalConverter> adc_analog_in;
std::unique_ptr<app::interfaces::IAnalogToDigitalConverter> adc_analog_out;
std::unique_ptr<app::interfaces::IAnalogToDigitalConverter> adc_digital_in;
std::unique_ptr<app::interfaces::IAnalogToDigitalConverter> adc_digital_out;
std::unique_ptr<app::interfaces::IDigitalToAnalogConverter> dac_digital_out;
std::unique_ptr<app::interfaces::ILedDriver> led_driver_1;
std::unique_ptr<app::interfaces::ILedDriver> led_driver_2;
std::unique_ptr<app::interfaces::ILedDriver> led_driver_3;
std::unique_ptr<app::interfaces::ISerialInterface> serial_0;
std::unique_ptr<app::interfaces::ISerialInterface> serial_1;
std::unique_ptr<app::interfaces::ISerialInterface> serial_2;

/**
 * @brief Initialisiert die Plattform, erstellt Hardware-Treiber und startet
 * Systemdienste.
 */
void SystemSetup() {
  // 1. Plattform initialisieren
  app::platform::Init();

  // 2. Hardware erstellen
  web_server = app::platform::CreateWebServer();
  adc_analog_in = app::platform::CreateAdc();
  adc_analog_out = app::platform::CreateAdc();
  adc_digital_in = app::platform::CreateAdc();
  adc_digital_out = app::platform::CreateAdc();
  dac_digital_out = app::platform::CreateDac();
  led_driver_1 = app::platform::CreateLedDriver();
  led_driver_2 = app::platform::CreateLedDriver();
  led_driver_3 = app::platform::CreateLedDriver();
  serial_0 = app::platform::CreateSerial(app::types::Serial::kUart);
  serial_1 = app::platform::CreateSerial(app::types::Serial::kRs485);
  serial_2 = app::platform::CreateSerial(app::types::Serial::kRs232);

  // 3. Wiring
  sys_ctx.frontend.web_server = web_server.get();

  sys_ctx.converter.adc[app::types::IO::kAnalogIn] = adc_analog_in.get();
  sys_ctx.converter.adc[app::types::IO::kDigitalIn] = adc_digital_in.get();
  sys_ctx.converter.adc[app::types::IO::kAnalogOut] = adc_analog_out.get();
  sys_ctx.converter.adc[app::types::IO::kDigitalOut] = adc_digital_out.get();

  sys_ctx.converter.dac[0] = dac_digital_out.get();

  sys_ctx.ui.led_drivers[0] = led_driver_1.get();
  sys_ctx.ui.led_drivers[1] = led_driver_2.get();
  sys_ctx.ui.led_drivers[2] = led_driver_3.get();

  sys_ctx.communication.serial[0] = serial_0.get();
  sys_ctx.communication.serial[1] = serial_1.get();
  sys_ctx.communication.serial[2] = serial_2.get();

  // =========================================================
  // 4. LOGIK-SERVICES ERSTELLEN & VERKABELN
  // =========================================================

  // 4.1 Basis-Services ohne Abhängigkeiten (Level 1)
  error_manager = std::make_unique<app::logic::ErrorManager>();
  process_imager = std::make_unique<app::logic::ProcessImager>();
  mailbox = std::make_unique<app::logic::Mailbox>();

  sys_ctx.logic.error_manager = error_manager.get();
  sys_ctx.logic.process_imager = process_imager.get();
  sys_ctx.logic.mailbox = mailbox.get();

  // 4.2 Höherwertige Services (Level 2 - brauchen den Context)
  serial_streamer = std::make_unique<app::logic::SerialStreamer>(sys_ctx);
  led_manager = std::make_unique<app::logic::LedManager>(sys_ctx);

  sys_ctx.logic.serial_streamer = serial_streamer.get();
  sys_ctx.logic.led_manager = led_manager.get();

  // =========================================================
  // 5. CONTROLLER (Level 3 - Orchestratoren)
  // =========================================================
  system_controller = std::make_unique<app::core::SystemController>(sys_ctx);

  api_controller =
      std::make_unique<app::logic::ApiController>(web_server.get(), sys_ctx);

  // 6. Starten
  api_controller->RegisterRoutes();
  app::platform::NetworkSetup();

  web_server->Start();
  system_controller->Initialize();
}

/**
 * @brief Prüft non-blocking, ob der Serielle Monitor verbunden ist
 * und auf einen Tastendruck wartet, um die Historie auszugeben.
 */
#ifdef ESP32_ENV
void HandleSerialTerminal() {
  static bool was_connected = false;
  bool is_connected = Serial;

  // Optionale Info, wenn der Monitor gerade frisch verbunden wurde
  if (is_connected && !was_connected) {
    Serial.println("\n\r[SYSTEM] Terminal verbunden. Druecke 'Enter'.");
  }
  was_connected = is_connected;

  if (is_connected && Serial.available()) {
    char c = Serial.read();

    if (c == '\n' || c == '\r') {
      while (Serial.available()) Serial.read();

      app::core::Logger::ProcessLogs([](const std::string& log_line) {
        Serial.println(log_line.c_str());
      });

      Serial.println("=================================================");
    }
  }
}
#endif

/**
 * @brief Führt zyklisch die Systemlogik aus.
 */
void SystemLoop() {
  if (system_controller != nullptr) {
    system_controller->RunSystemLogic();
  }
}

// =============================================================================
// ================== ENTRY LAYER (Technische Einstiegspunkte) =================
// =============================================================================

#ifdef ESP32_ENV
void setup() { SystemSetup(); }
void loop() {
  if (loop_delay.isReady()) {
    SystemLoop();
    HandleSerialTerminal();
  }
}
#else
int main() {
  SystemSetup();

  while (true) {
    SystemLoop();
    std::this_thread::sleep_for(std::chrono::milliseconds(10));
  }
  return 0;
}
#endif

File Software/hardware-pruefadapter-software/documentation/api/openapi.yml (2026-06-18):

openapi: "3.1.2"
info:
  title: Hardware Prüfadapter API
  description: |
    REST API zur Steuerung des ESP32 Prüfadapters.
    Dient zur Abfrage von Sensorwerten (Analog/Digital) und zum Setzen von Ausgängen.
    
    **Neu in 2.1.0:** Alle Endpunkte verfügen nun über einen integrierten Überlastungsschutz (Bouncer). 
    Wird das Limit an gleichzeitigen Verbindungen überschritten, antwortet die API sofort mit HTTP 503.
  version: "2.1.0"
  contact:
    name: Techniker Team 2026 (Mika Müller, Nico Stein, Lukas Horst)
    email: m.mueller@sotec.eu

servers:
  - url: http://192.168.4.1/api/v1
    description: ESP32 Production Server
  - url: http://localhost:8080/api/v1/
    description: Local Simulation (WSL/PC)

paths:
  # ==========================================
  # SYSTEM STATUS & LOGS
  # ==========================================
  /system/status:
    get:
      summary: Systemstatus abrufen
      description: Liefert Vitalwerte (Uptime, RAM) und den Fehlerstatus des Systems.
      tags:
        - System
      responses:
        "200":
          description: Erfolgreiche Abfrage
          content:
            application/json:
              schema:
                $ref: "#/components/schemas/SystemStatus"
        "503":
          $ref: "#/components/responses/503Overload"

  /system/logs:
    get:
      summary: System-Logs (Historie) abrufen
      description: Lädt die im RAM gepufferten Log-Einträge. Dient zur initialen Befüllung des Terminals.
      tags:
        - System
      responses:
        "200":
          description: Erfolgreiche Abfrage
          content:
            application/json:
              schema:
                $ref: "#/components/schemas/LogsResponse"
        "503":
          $ref: "#/components/responses/503Overload"

  /system/logs/stream:
    get:
      summary: Live-Log-Stream (Server-Sent Events)
      description: |
        Öffnet eine dauerhafte SSE-Verbindung. Der Server pusht neue Daten in Echtzeit.
        Das System nutzt verschiedene Event-Typen:
        - Event 'log': Reguläre System-Logs.
        - Event 'serial': Serielle Datenblöcke aus den UART Puffern. Format: {"source": "UART|RS232|RS485", "data": "..."}
      tags:
        - System
      responses:
        "200":
          description: SSE Verbindung hergestellt.
          content:
            text/event-stream:
              schema:
                type: string
        "503":
          $ref: "#/components/responses/503Overload"

  # ==========================================
  # I/O BULK OPERATIONS (Das ganze Dashboard auf einmal)
  # ==========================================
  /io:
    get:
      summary: Komplettes I/O Prozessabbild abrufen
      description: Liefert alle analogen und digitalen Eingänge sowie die Readback-Werte und Zustände der Ausgänge in einem einzigen Request. (Performance-optimiert für Dashboards).
      tags:
        - I/O
      responses:
        "200":
          description: Erfolgreiche Abfrage des gesamten I/O-Status.
          content:
            application/json:
              schema:
                $ref: "#/components/schemas/IoAllResponse"
        "503":
          $ref: "#/components/responses/503Overload"

  # ==========================================
  # I/O EINZELKANÄLE
  # ==========================================
  /io/{technologyType}/{direction}/{channel}:
    get:
      summary: Einzelnen Kanal abrufen
      description: Lädt den Wert eines spezifischen Kanals.
      tags:
        - I/O
      parameters:
        - name: technologyType
          in: path
          required: true
          schema:
            type: string
            enum: [analog, digital]
        - name: direction
          in: path
          required: true
          schema:
            type: string
            enum: [input, output]
        - name: channel
          in: path
          required: true
          description: Kanalnummer (0-3)
          schema:
            type: integer
            minimum: 0
            maximum: 3
      responses:
        "200":
          description: OK
          content:
            application/json:
              schema:
                oneOf:
                  - $ref: "#/components/schemas/AnalogResponse"
                  - $ref: "#/components/schemas/DigitalResponse"
        "503":
          $ref: "#/components/responses/503Overload"
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

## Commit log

2026-06-18 Fertiger Projektupload
    [0ZCJ0010FF2E.step, 0ZCM0002FF2G.step, 0ZCM0005FF2G.step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]
2026-06-18 add: Hardwareänderungshinweise; update: readme.md; fix: Versionierung im Namen der bom, designator und position datei
    [hardwarepruefadapter_v1_bom.csv, hardwarepruefadapter_v1_designators.csv, hardwarepruefadapter_v1_positions.csv]

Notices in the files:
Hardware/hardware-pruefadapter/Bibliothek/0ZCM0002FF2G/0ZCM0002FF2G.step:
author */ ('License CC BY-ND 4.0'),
